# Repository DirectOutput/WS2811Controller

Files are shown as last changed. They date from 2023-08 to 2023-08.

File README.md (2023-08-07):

# WS2811 Controller
Source Code for the Atmel based WS2811 controller.

This is just old code and board designs which I found on my backup disks. There are 3 different version of the code and several versions of the board design. In some directories there are a few word and pdf files that explain some of the details. Cant say for sure if some of all this any good and what that would be. 

The assembly code was written in Atmel Studio. The boards where made with Eagle.

Feel free to use it in any way you like. Unfortunately, I cant really help with questions, since I have not touched all this for the last 8 years.

7.8.2023

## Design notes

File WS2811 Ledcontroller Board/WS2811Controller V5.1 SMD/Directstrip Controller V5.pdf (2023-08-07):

# Direct Strip Controller

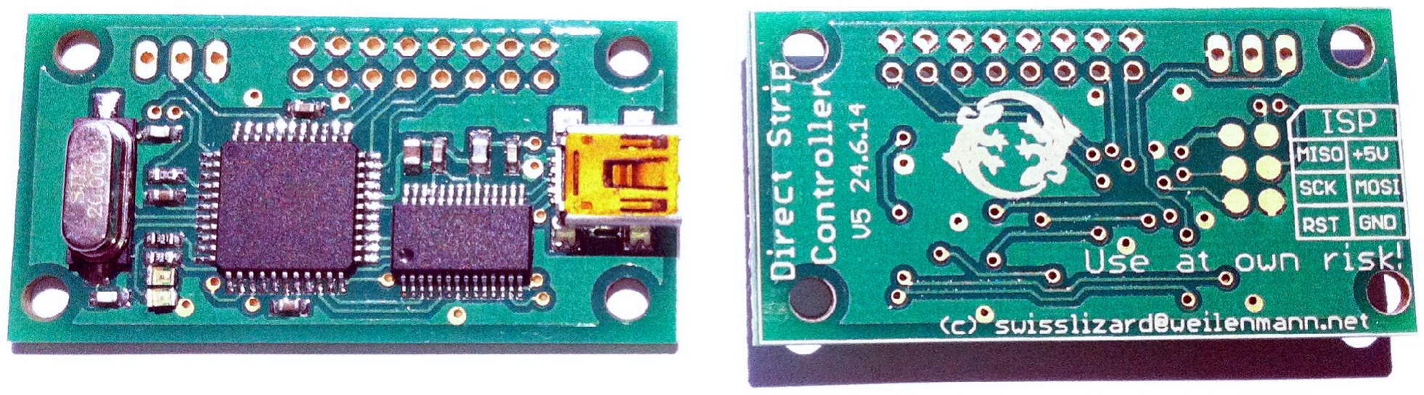
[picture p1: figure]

### made for

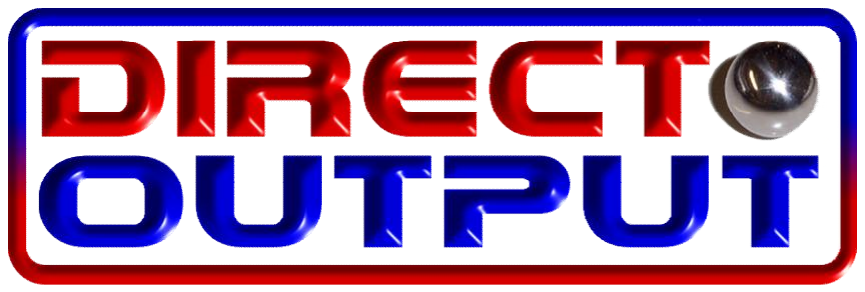
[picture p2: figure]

by

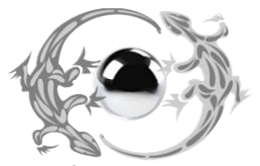
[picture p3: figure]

### Swisslizard

## Table of Contents

Direct Strip Controller | 1
Table of Contents | 2
Introduction | 3
Software | 3
Driver | 3
Firmware | 3
DirectStrip Controller Configurator | 3
Main Window | 4
Update firmware | 4
Communication Protocol | 6
Clear Data Buffer | 6
Receive Data | 6
Output Data | 7
Get Firmware Version | 7
Start Bootloader | 7
No acknowledge/Nack situations | 7
Wiring Instructions for Led Strips | 8
Step 1: Connect led strips | 8
Step 2: Connect power supply | 8
Step 3: Connect USB | 9
DirectOutput framework configuration | 10
Cabinet config file | 10
DirectStripController section | 11
LedStrip toy sections | 11
LedWizEquivalent section | 13
Table configurations | 14
Trigger parameters | 14
General parameters | 14
Matrix/area effect parameters | 15

## Introduction

This small controller boards allows you to control led strips using WS2812 or
WS2811 leds from your computer. The hardware is prepared to support other types of led strips as well, but the firmware still needs to be extended with some extra logic for those strips.

It consists of a USB chip which allows for fast communication with the PC and a Atmel micro controller which receives the data from the USB interface and generates the signal for the led strips.

## Software

### Driver

The controller board uses the FT245R chip from FTDI. To use the board you will have to install the appropriate driver, which is available for download on FTDIs page: http://www.ftdichip.com/Drivers/D2XX.htm
DOF needs only the D2XX drivers, but you might want to install the VCP drivers as well, since those are very easy to use if you want to write your own code.

### Firmware

The firmware has been developed using Atmel Studio 6, which is available from Atmels website. The firmware has been written in assembler to allow for max speed and precise cycle accurate output signals.

### DirectStrip Controller Configurator

This small tool allows you to change the number of your controller board, update the firmware and to configure the settings of a new FT245 chip so it is recognized as a DirectStrip strip controller.

Main Window

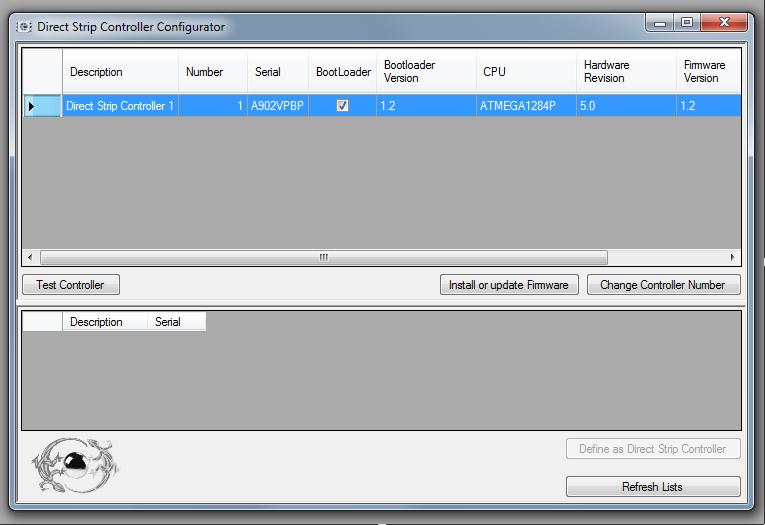
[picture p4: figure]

The upper list of the main window shows the currently detected DirectStrip controllers.
For controllers which have the bootloader installed, you can update the firmware, change the controller number and send some test patterns to a connected ledstrip.

The bottom list shows currently detected FT245 based units, including not configured DirectStrip controllers, but also other types of controllers which use the same type of hardware interface (e.g. Sainsmart). If you define a listed unit which is not a DirectStrip controller as a DirectStrip controller is might become unusable. So be sure you know what you are doing.

Update firmware
Warning!!!
Do not update your firmware for fun! The cpu of the controller has a limited number of write cycles and if something goes wrong during the firmware update your controller might become unusable.

The firmware update wizard allows you to update the firmware of you controller board in three easy steps.

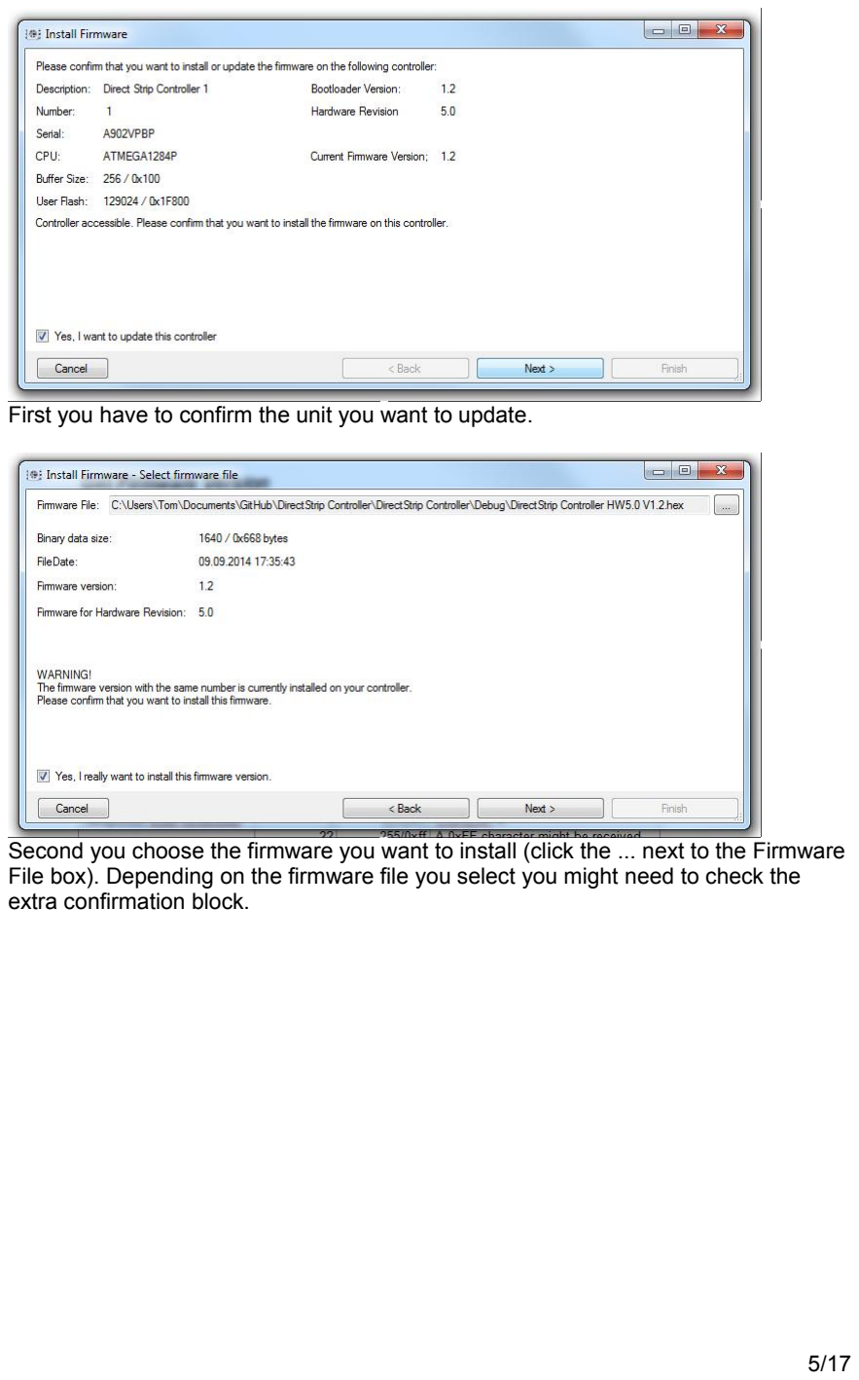
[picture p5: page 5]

First you have to confirm the unit you want to update.

Second you choose the firmware you want to install (click the ... next to the Firmware File box). Depending on the firmware file you select you might need to check the extra confirmation block.

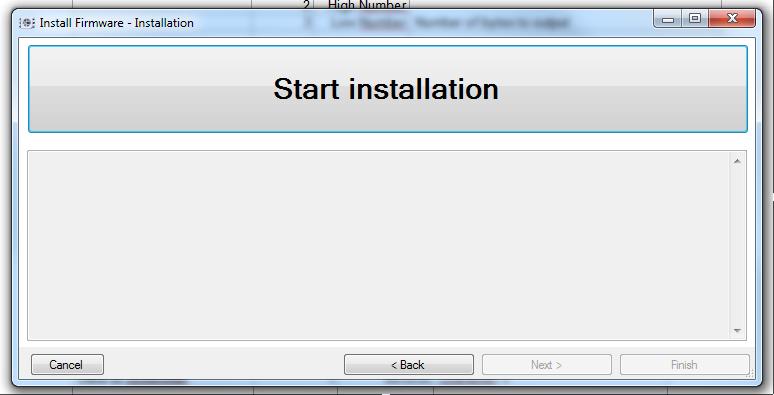
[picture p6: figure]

Third you start the installation of the firmware.
During the installation a progress bar and a log will keep you informed whats going on and whether the firmware installation has been successful or not.

## Communication Protocol

The protocol of the controller board works in a simple serial fashion. Depending on the drivers you have installed, you can even access the board like a normal com port.

All commands for the controller start with a single character, specifying the
command, followed by additional parameter bytes.
Every command is answered by the controller with single byte signalling acknowledge (A) or no acknowledge (N) of the last command.

### Clear Data Buffer

Clears the data buffer on the controller.
Byte
Nr | Value Remark
Data to controller | 1 67/0x43 Character R
Response from controller | 1 65/0x41 Character A

### Receive Data

Tells the controller to receive a block of data and put it into the data buffer.
If you write your own software it is recommended that you choose a fast implementation when using this command, since the controller is able to receive data at high rates.
| Byte Nr | Value Remark
Data to controller | 1 | 82/0x52 Character R
| 2 | High Number
| 3 | Low Number Total number of data bytes to receive
| 4 | First data byte
| 5 | Second data byte

| …. | More data bytes
| Num
| Bytes-1 | Second last data byte
| Num Bytes | Last data byte
Response from controller | 1 | 65/0x41 Character A

### Output Data

Sends data from the data buffer to the led strip. Normally this command will be used after the receive data command.

| Byte Nr | Value Remark
Data to controller | 1 | 79/0x4F Character 0
2 | High Number
| 3 | Low Number Number of bytes to output
Response from controller | 1 | 65/0x41 Ack is sent after all bytes have been sent to the led strip.

### Get Firmware Version

Gets the version of the currently installed firmware.
| Byte Nr | Value Remark
Data to controller | 1 | 86/0x56 Character V
Response from controller | 1 | 62/0x3E Character >
| 2 | 3/0x03 Number of answer bytes
3 Version major
4 Version minor 0-99
| 5 | 65/0x41 Ack

### Start Bootloader

This commands starts the bootloader of the controller board by triggering a reset of the controller. Please take note that the controller doesn't receive any data for the next 3 seconds after the ack of the command.
| Byte Nr | Value Remark
Data to controller | 1 | 90/0x5A Character Z
Response from controller | 1 | 65/0x41 Character A
2? | 255/0xff

A 0xFF character might be received depending due to pin changes during the reset.

### No acknowledge/Nack situations

If the above commands are used as expected, nack or no answer situations should at least in theory never occur. If you receive a nack anyway, there is likely a bug in your program, the firmware or less likely some problem receiving the data hardware wise. A simple procedure to react on a nack or missing answer is to send 0 bytes until another nack is received. After that second nack has been received the controller should be ready to receive the next command.

## Wiring Instructions for Led Strips

### Step 1: Connect led strips

Connect your WS2812 led strips to the controller board. You'll have to connect 2 wires: Data and Ground (GND). Both can be found on the strip connector of the controller board.

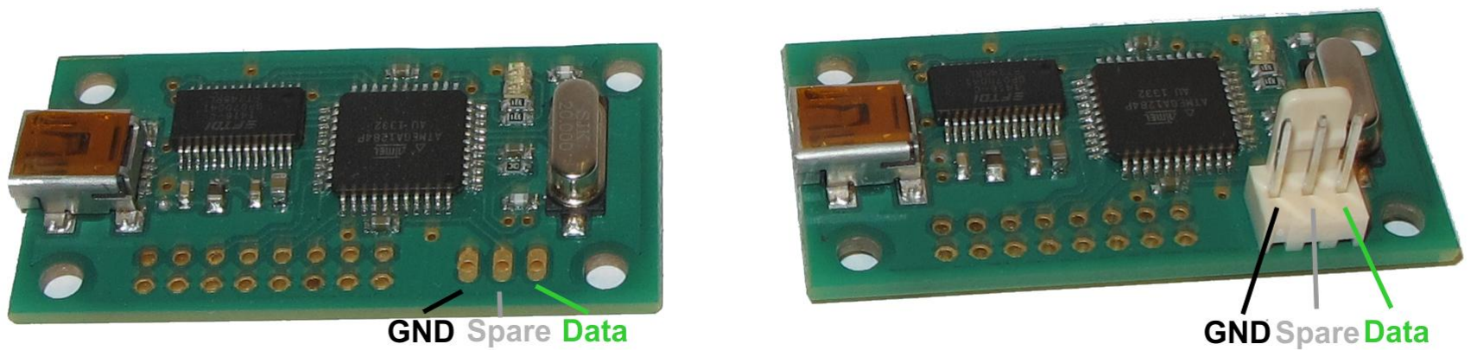
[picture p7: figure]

Warning!
Dont connect anything to the third pin marked Spare of the led strip connector. It is not yet active and reserved for possible future support of other types of led strips.

### Step 2: Connect power supply

Connect your led strips to a suitable power supply. The controller board cant supply power for the led strips and doesn't have a power connector for that purpose.

Ledstrips can consume a lot of power. Typically a led strip based on WS2812 leds will consume up to 60ma (20ma for each color) per led, e.g. if you use 1 meter of strip with 60 leds you will need a power supply which can deliver at least 3.6A (60 * 60ma=3600ma).

For me power supplies from Meanwell have always worked well so far and are available in different strengths.

Voltage for the WS2812 led strips is 5 volts.

Remarks:
- If you use a long led strip, be sure to inject power not only at the start of the strip, but also after at least every 150-200 leds. Otherwise your strip will heat up to much, brightness and color of the leds change and operation will
become unstable.
- The longer the cable from the power supply to the led strip gets and the longer the led strip is, the thicker the cable should be.
- Always keep in mind that those strips operate on 5volts only and that the currents (Ampere/A) required can be quite high. High currents can develop a lot of heat if you dont do your wiring properly!

### Step 3: Connect USB

Connect the controller board to your computer using a normal USB cable.

To start using the board check the chapter on the software in drivers.

## DirectOutput framework configuration

### Cabinet config file

To use this controller board with the DirectOutput framework (DOF) you will need a cabinet config file. The cabinet config file is a XML file with the following minimal structure:

<?xml version="1.0"?>
<Cabinet xmlns:xsi="http://www.w3.org/2001/XMLSchema-instance"xmlns:xsd="http://www.w3.org/2001/XMLSchema">
<Name>Name of the cabinet</Name>
<OutputControllers>
... configuration of any number of output controllers ... </OutputControllers>
<Toys>
... configuration of any number toys ...
</Toys>
</Cabinet>

To configure the controller board for DOF you need to specify a DirectStripController in the OutputControllers section, one or several LedStrip toys and a LezWizEquivalent toy in the Toys section.

<?xml version="1.0"?>
<Cabinet xmlns:xsi="http://www.w3.org/2001/XMLSchema-instance"xmlns:xsd="http://www.w3.org/2001/XMLSchema">
<Name>Name of the cabinet</Name>
<OutputControllers>
<DirectStripController>
<Name>ControllerName</Name> <ControllerNumber>1</ControllerNumber> <NumberOfLeds>235</NumberOfLeds> </DirectStripController>
</OutputControllers>
<Toys>
<LedStrip>
<Name>BackBoard</Name>
<Width>32</Width>
<Height>3</Height>
<LedStripArrangement>LeftRightTopDown</LedStripArrangement> <ColorOrder>GRB</ColorOrder> <FirstLedNumber>1</FirstLedNumber> <FadingCurveName>SwissLizardsLedCurve</FadingCurveName> <OutputControllerName>ControllerName</OutputControllerName> </LedStrip>
<LedStrip>
<Name>SideboardRight</Name>
<Width>1</Width>
<Height>65</Height>
<LedStripArrangement>TopDownLeftRight</LedStripArrangement> <ColorOrder>GRB</ColorOrder> <FirstLedNumber>97</FirstLedNumber> <FadingCurveName>SwissLizardsLedCurve</FadingCurveName> <OutputControllerName>ControllerName</OutputControllerName> </LedStrip>
<LedStrip>
<Name>SideboardLeft</Name>
<Width>1</Width>
<Height>65</Height>
<LedStripArrangement>TopDownLeftRight</LedStripArrangement> <ColorOrder>GRB</ColorOrder> <FirstLedNumber>167</FirstLedNumber> <FadingCurveName>SwissLizardsLedCurve</FadingCurveName> <OutputControllerName>ControllerName</OutputControllerName> </LedStrip>
<LedWizEquivalent>
<Name>LedWizEquivalent50</Name> <LedWizNumber>50</LedWizNumber> <Outputs>
<LedWizEquivalentOutput>

<OutputName>BackBoard</OutputName> <LedWizEquivalentOutputNumber>1</LedWizEquivalentOutputNumber> </LedWizEquivalentOutput>
<LedWizEquivalentOutput>
<OutputName>SideboardRight</OutputName>

<LedWizEquivalentOutputNumber>4</LedWizEquivalentOutputNumber> </LedWizEquivalentOutput>
<LedWizEquivalentOutput>
<OutputName>SideboardLeft</OutputName>

<LedWizEquivalentOutputNumber>10</LedWizEquivalentOutputNumber> </LedWizEquivalentOutput>
</Outputs>
</LedWizEquivalent>
</Toys>
</Cabinet>

DirectStripController section
The following section defines the output controller:

<DirectStripController>
<Name>ControllerName</Name> <ControllerNumber>1</ControllerNumber> <NumberOfLeds>235</NumberOfLeds> </DirectStripController>
- Name can be anything you like.
- ControllerNumber is the number of your controller board. You can use the tool supplied with the board to change the controller number of your boards.
- NumberOfLeds is the total number of RGB leds on your ledstripe. This value defines how much data DOF sends to the controller board and how much memory it reserves for the led strip data.

LedStrip toy sections
The LedStrip toy sections look a follows:

<LedStrip>
<Name>BackBoard</Name>
<Width>32</Width>
<Height>3</Height>
<LedStripArrangement>LeftRightTopDown</LedStripArrangement> <ColorOrder>GRB</ColorOrder> <FirstLedNumber>1</FirstLedNumber> <FadingCurveName>SwissLizardsLedCurve</FadingCurveName> <OutputControllerName>ControllerName</OutputControllerName> </LedStrip>
- Name can be anything you like.
- FirstLedNumber is the number of the first led of the strip which is part of the toy.
- OutputControllerName is the name of the output controller which you have defined in the DirectStripController section.
- Width and Height define the size of your led stripe arrangement. This allows you to define a matrix of leds. If you use just a single strip in your arrangement, set these values based on the main direction of your ledstrip, e.g. width: 32, height: 1 for a single strip on a backboard or width:1, height:65 for a single strip on a sideboard of your cabinet. If you have a matrix set width and height to the number of leds in x resp y direction.
- LedStripArrangement is used to tell DOF how the ledstrips in your matrix are wired. If your arrangement consist of a single strip this settings doesn't have any effect. The following values are supported:

- LeftRightTopDown
- LeftRightBottomUp
- RightLeftTopDown
- RightLeftBottomUp
- TopDownLeftRight
- TopDownRightLeft
- BottomUpLeftRight
- BottomUpRightLeft
- LeftRightAlternateTopDown
- LeftRightAlternateBottomUp
- RightLeftAlternateTopDown
- RightLeftAlternateBottomUp
- TopDownAlternateLeftRight
- TopDownAlternateRightLeft
- BottomUpAlternateLeftRight
- BottomUpAlternateRightLeft
- ColorOrder defines the order of colors of the RGB leds on your led strip. The following values are supported:
- RGB = Red-Green-Blue (usual color order)
- RBG = Red - Blue - Green
- GRB = Green - Red - Blue (WS2812 led chips are using the scheme)
- WS2812 = WS2812 led chip (uses green - red - blue color order)
- GBR = Green - Blue - Red
- BRG = Green - Blue - Red
- BGR = Blue - Green - Red
- FadingCurveName allows you to define which fading cruve to use for your leds. Fading curves can be used to adjust the brightness of the leds to the brigthness perception of the human eye or also to achieve special effects. DOF has a number of predefined fading curves, but user defined curves (see DOF docu for details) can be used as well. The following predefined curves are available:
- Linear = A linear curve, where each element will map to a value which is equal to the element index (0=0, 1=1 .... 254=254,255=255).
- Linear0To224 = A linear curve, which maps 0 to 255 value range into a new range of 0 to 224.
- Linear0To192 = A linear curve, which maps 0 to 255 value range into a new range of 0 to 192.
- Linear0To160 = A linear curve, which maps 0 to 255 value range into a new range of 0 to 160.
- Linear0To128 = A linear curve, which maps 0 to 255 value range into a new range of 0 to 128.
- Linear0To96 = A linear curve, which maps 0 to 255 value range into a new range of 0 to 96.
- Linear0To64 = A linear curve, which maps 0 to 255 value range into a new range of 0 to 64.
- Linear0To32 = A linear curve, which maps 0 to 255 value range into a new range of 0 to 32.
- Linear0To16 = A linear curve, which maps 0 to 255 value range into a new range of 0 to 16.
- InvertedLinear = This is a inverted linear curve where 255=0, 254=1 and so on until 1=254 and 0=255.

- SwissLizardsLedCurve = A fading curve for leds defined by SwissLizard. This curve is not fully correct when it comes to theoretically needed mapping values, but it is some kind of compromise between possible value range and the desired values.

LedWizEquivalent section
The LedWizEquivalent section allows DOF to map effect settings from ini files with table configurations to the led strips.

<LedWizEquivalent>
<Name>LedWizEquivalent50</Name> <LedWizNumber>50</LedWizNumber> <Outputs>
<LedWizEquivalentOutput>
<OutputName>BackBoard</OutputName> <LedWizEquivalentOutputNumber>1</LedWizEquivalentOutputNumber> </LedWizEquivalentOutput>
<LedWizEquivalentOutput>
<OutputName>SideboardRight</OutputName> <LedWizEquivalentOutputNumber>4</LedWizEquivalentOutputNumber> </LedWizEquivalentOutput>
<LedWizEquivalentOutput>
<OutputName>SideboardLeft</OutputName> <LedWizEquivalentOutputNumber>10</LedWizEquivalentOutputNumber> </LedWizEquivalentOutput>
</Outputs>
</LedWizEquivalent>
- Name can be anything you like.
- LedWizNumber is the number of the ini file to be associated with the LedWizEquivalent toy.
- The output section defines which column of the ini file is mapped to which led strip toy:
- OutputName has to specify the name of the LedStrip toy to be controlled. Take note that this is different from normal OutputName settings for LedWizEquivalent toys, where the name of a output is defined.
- LedWizEquivalentOutputNumber is column of the ini file which is to be associated with the led strip specified in OutputName.

### Table configurations

The led strips connected to the contoller board can be controlled by ini files like other toy.

The same parameters as for other toys are accepted, but the are some additional paras for toys consisting of more than one element.

Trigger parameters
The first part of a setting defines how the setting/effect is triggered and must always be one of the following:
- TableElementTypeChar plus Number (e.g. S48 for solenoid 48) determines which table element is controlling the specified effect.
- List of TableElementTypeChars plus Numbers delimited by | (e.g.
S48|W12|L59). This setting assigns the same effect to all table elements in the list.
- Condition which controlles wether the effect is triggered or not. Conditions must always be in brackets. Example: (S48=1 and W29=0 and (L59=1 or L43<>0)).
- On resp. 1 turns the specified effect constantly on.
- B defines a static (not externaly controlled) blinking.

General parameters
The second and following parts of a setting can contain one or several of the following paramaters:
- Color name as specified in the colors section of the file. Only valid as the second value (e.g. S48 Blue).
- Hex color definition (e.g. #ff0000ff for opaque red). Take note that these color definitions allow for values from 0-255 in contrast to the colors section which only support 0-48. Hex color definitions can contain 3 or 4 parts (without or with alpha value). Setting is only accepted as the second value.
- Blink defines blinking with a default interval of 500ms.
- I{Number} defines a intensity/level of the output. The number can either be specified as a decmal number between 0 (e.g. I0 for off) and 48 (e.g. I48 for fully on) or as a hexadecimal number between 00 (off) and FF (fully on) with a leading # (e.g. I#80 for 50% power). This settings does only have a effect for settings without a color definition.
- L{Number} defines the layer on which the setting operates. In most cases the setting is not required, since DOF will assign ascending layer numbers to the settings for a column anyway.
- W{NumberOfMilliseconds} defines a wait period resp. delay before the effect executes after it has been triggered.
- M{NumberOfMilliseconds} defines the minimum duration for the effect in milliseconds.
- Max{NummberOfMilliseconds} defines the maximum duration for the effect in milliseconds.
- F{NumberOfMilliseconds}, FU{NumberOfMilliseconds}, FD{NumberOfMilliseconds} are used to specify the fading duration in milliseconds. F sets the duration for both fading up and down, FU controls fading up only and FD fading down only.
- E{NumberOfMilliseconds} specifies a extended duration in milliseconds for the effect (after it has been turned off).
- BL{Number} specifies the value of the blink effect during the low period of the blinking (High value=trigger value of the effect, typicaly 255).
- BPW{Percentage} defines the blink pulse width in percent of the blink interval. Valid values are 1-99, default value if not defined is 50.
- BNP{NumberOfMilliseconds} defines the interval (duration of one on/off period) for nested blinking. This allows to define a second level of blinking within the on period of the normal blinking.
- BNPW{Percentage} defines the blink pulse width for nested blinking in percent of the blink interval.
- Invert inverts the effect, so the effect will be active when it is normaly inactive and vice versa.
- NoBool indicates that the trigger value off the effect is not to be treated as a boolean value resp. that the daufault mapping of the value to 0 or 255 (255 for all values which are not 0) should not take place. The number can either be specified as a decmal number between 0 and 48 (e.g. BL3) or as a hexadecimal number between 00 and FF with a leading # (e.g. BL#30).
- Numeric Values without any extra character can be used to specify the duration of the effect or the blinking behaviour. If blinking has been defined, one or two numeric values are parsed. Value 1 controls the blink interval in milliseconds, while value 2 defines the number of blinks. If no blinking has been defined, only one numeric values which is used to defined the duration of the effect in milliseconds is parsed.

Matrix/area effect parameters
For adressable ledstrips and other toys which implement the IMatrixToy interface the following extra parameters can be used to control the hardware referenced by the matrix. For settings controlling a matrix you have to use at least one of these paras, so DOF realizes that a matrix/area is to be controlled.

The matrix effects and parameters can be combined with the general paras mentioned above.

General Matrix Paras

The following 4 paramaters are specifying the area of a matrix which is to be influenced by a matrix effect:

- AL{LeftPosition} defines the left of the upper left corner of the area of the matrix which is to be controlled by the effect. Position is expressed in percent of the matrix width (0-100).
- AT{TopPosition} defines the upper part of the upper left corner of the area of the matrix which is to be controlled by the effect. Position is expressed in percent of the matrix height (0-100).
- AW{Width} defines the width of the area of the matrix which is to be controlled by the effect. Width is expressed in percent of the matrix width (0-100).

- AH{Height} defines the height of the area of the matrix which is to be controlled by the effect. Height is expressed in percent of the matrix height (0-100).

Shift Effect Paras
The matrix shift effect moves a color/value with a defineable direction, speed and acceleration through the matrix:
- AD{DirectionCharacter} defines the direction for area effects having a direction parameter (e.g. the ColorShiftEffect). Valid directions are: R-Right, L-Left, U-Up, D-Down.
- AS{Speed} defines the speed for matrix effects have a speed parameter (e.g. the ColorShiftEffect) expressed in percent of the effect area per second. 100 will shift through the effect area in one second, 400 will shift through the effect area in 1/4 second. Min. speed is 1, max. speed is 10000.
- AA{Acceleration} defines the acceleration of the speed for matrix effects (e.g. ColorShiftEffect), expressed in percent of the effect area per second. Acceleration can be positive (speed increases) or negative (speed decreases). Speed will never decrease below 1 and never increase above 10000.

Flicker Effect Paras
The flicker effect generates random flickering with a defineable density and duration for the single flickers:
- AFDEN{Percentage} defines the density for the flicker effect. Density is express in percent a has a valid value range of 1 to 99.
- AFMIN{DurationInMilliseconds} defines the min duration for the flicker of a single led in milliseconds.
- AFMAX{DurationInMilliseconds} defines the max duration for the flicker of a single led in milliseconds.

Bitmap Effect Paras
DOF can display a part of a bitmap image on a matrix toy. The defined part of the bitmap is scaled to the size of the matrix, so the actual resolution of the matrix does not matter. If you specify a bitmap effect by using one of the following parameters, DOF will try to load a bitmap image (gif, png, jpg and more should all work) from the same directory as the ini file. The bitmap image has to be named like the short rom name in the first collumn of the ini file (e.g. mm.png for Medival Madness or afm.gif for Attack from Mars).
- ABL{LeftPostionInPixels} defines the left/horizontal part of the upper left corner of the part of the bitmap to be displayed. Defaults to 0 if not specified.
- ABW{WidthInPixels} defines the width of the part of the bitmap to be displayed. Defaults to the total width of the image if not specified.
- ABT{TopPositionInPixels} defines the upper/vertical part of the upper left corner of the part of the bitmap to be displayed. Defaults to 0 if not specified.
- ABH{HeightInPixels} specifies the height of the part of the bitmap to be displayed. Defaults to the total height of the image if not specified.
- ABF{FrameNumber} indicates the frame of the image to be displayed. This setting is only relevant if you use animated gif images. Defaults to the first frame of the animated gif if not specified.

Bitmap Animation Paras
The following extra paras can be used in addition to the bitmap paras to animate the bitmap display on the matrix:
- AAC{CountOfFrames} specifies the total number of frames of the animation.
- AAF{FramesPerSecond} specifies the number of frames per second.
- AAD{FrameExtractionDirectionCharacter} defines the direction in which DOF moves through the source image to generate the animation. Valid values for the direction character are L=Left, D=Down, F=Frame (for animated gifs)
- AAS{FrameExtrationStepSize} defines the size of the steps DOF takes to move through the source image to generate the animation. The step size is either in pixels or in frames.
- AAB{AnimationBehaviourCharacter} defines the behaviour when the animation is triggered. Valid values are O=show animation once, L=Start at beginning and show animation in a loop (default), C=Continue at last position and show animation in a loop

The following image might give a a better idea what these parameters do. It shows the behaviour for a setting like S48 AL0 AT10 AW100 AH20 AAC116 AADD AAS5 AAF30 AABL.

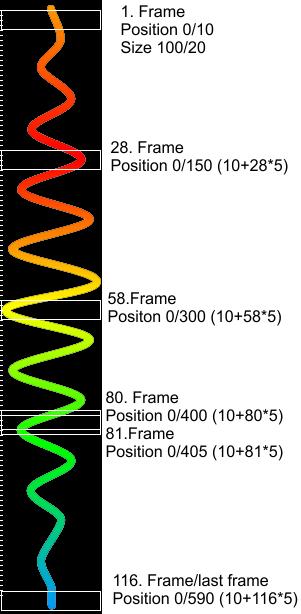
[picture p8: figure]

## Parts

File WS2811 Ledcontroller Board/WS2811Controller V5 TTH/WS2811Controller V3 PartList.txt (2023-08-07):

Partlist

Exported from WS2811Controller.sch at 29.04.2014 12:13:41

EAGLE Version 6.4.0 Copyright (c) 1988-2013 CadSoft

Assembly variant: 

Part             Value                 Device                Package                Library          Sheet

AVR-ISP                                AVR-ISP-6             AVR-ISP-6              0_avr            1
C1               100nF                 C-EU025-025X050       C025-025X050           0_Standard-Parts 1
C2               22pf                  C-EU025-025X050       C025-025X050           0_Standard-Parts 1
C3               22pf                  C-EU025-025X050       C025-025X050           0_Standard-Parts 1
C4               100nF                 C-EU025-025X050       C025-025X050           0_Standard-Parts 1
EXTCONNECTOR                           22-27-2101-10         6410-10                con-molex        1
IC1              MEGA164P/324P/644P-PU MEGA164P/324P/644P-PU DIL40                  0_avr            1
LED1                                   LED3MM                LED3MM                 0_Led            1
LED2                                   LED3MM                LED3MM                 0_Led            1
Q1               20Mhz                 CRYSTALHC49U-V        HC49U-V                0_tom parts      1
R1               10k                   R-EU_0207/10          0207/10                0_Standard-Parts 1
R2               330                   R-EU_0207/10          0207/10                0_Standard-Parts 1
R3               330                   R-EU_0207/10          0207/10                0_Standard-Parts 1
SPARKFUN_FT245RL                       FT245RL_BREAKOUTBOARD SPARKFUN_FT245RL_BOARD Sparkfun         1
STRIP1                                 22-27-2031-03         6410-03                con-molex        1

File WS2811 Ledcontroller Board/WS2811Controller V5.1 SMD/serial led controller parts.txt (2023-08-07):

Partlist

Exported from serial led controller.brd at 24.06.2014 08:57:33

EAGLE Version 6.4.0 Copyright (c) 1988-2013 CadSoft

Assembly variant: 

Part            Value                 Package      Library          Position (inch)       Orientation

+5V                                   TP19R        testpad          (0.425 0.6)           MR270
C1              100nF                 C0603K       rcl              (0.8125 0.7)          R180
C2              22pf                  C0603K       rcl              (0.28125 0.125)       R180
C3              22pf                  C0603K       rcl              (0.40625 0.625)       R180
C4              10n                   C0603K       rcl              (1.4125 0.5625)       R270
C5              100nF                 C0603K       rcl              (0.425 0.43125)       R180
C6              100nF                 C0603K       rcl              (1.2 0.5625)          R270
C7              10uf                  C0603K       rcl              (1.125 0.5625)        R270
C8              100nF                 C0603K       rcl              (0.7875 0.1)          R0
EXT_PORT                              2X08         pinhead          (1.15 0.85)           R0
GND                                   TP19R        testpad          (0.425 0.4)           MR270
IC1             MEGA1284              TQFP44       0_avr            (0.775 0.4)           R0
IC2             FT245RL               SSOP28DB     ftdichip-3       (1.275 0.3)           R0
L1              BLM21AG 601           L805         0_Standard-Parts (1.31875 0.56875)     R270
LED1Y           Yellow                CHIP-LED0603 led              (0.425 0.1375)        R270
LED2R           Red                   CHIP-LED0603 led              (0.425 0.1875)        R270
MISO                                  TP19R        testpad          (0.525 0.6)           MR270
MOSI                                  TP19R        testpad          (0.425 0.5)           MR270
Q1              20Mhz                 SM49         crystal          (0.24375 0.45625)     R90
R1              10k                   R0603        0_Standard-Parts (0.425 0.49375)       R0
R2              330                   R0603        0_Standard-Parts (0.425 0.3)           R180
R3              330                   R0603        0_Standard-Parts (0.425 0.24375)       R180
RST                                   TP19R        testpad          (0.525 0.4)           MR270
SCK                                   TP19R        testpad          (0.525 0.5)           MR270
STRIP_CONNECTOR                       6410-03      con-molex        (0.45 0.85)           R180
X1              MINI-USB-UX60A-MB-5ST UX60A-MB-5ST con-hirose       (1.65 0.4875)         R180

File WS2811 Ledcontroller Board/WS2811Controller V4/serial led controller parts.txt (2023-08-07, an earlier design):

Partlist

Exported from serial led controller.brd at 05.06.2014 11:07:59

EAGLE Version 6.4.0 Copyright (c) 1988-2013 CadSoft

Assembly variant: 

Part            Value                 Package      Library          Position (mm)         Orientation

C1              100nF                 C0603K       rcl              (20.6375 17.78)       R180
C2              22pf                  C0603K       rcl              (7.14375 3.175)       R180
C3              22pf                  C0603K       rcl              (10.31875 15.875)     R180
C4              10n                   C0603K       rcl              (35.8775 14.2875)     R270
C5              100nF                 C0603K       rcl              (10.795 10.95375)     R180
C6              100nF                 C0603K       rcl              (30.48 14.2875)       R270
C7              10uf                  C0603K       rcl              (28.575 14.2875)      R270
C8              100nF                 C0603K       rcl              (20.0025 2.54)        R0
IC1             ATMEGA1284            TQFP44       0_avr            (19.685 10.16)        R0
IC2             FT245RL               SSOP28DB     ftdichip-3       (32.385 7.62)         R0
L1              1.5A/307              R0603        0_Standard-Parts (33.655 14.2875)      R270
LED1                                  CHIP-LED0603 led              (10.795 3.4925)       R270
LED2                                  CHIP-LED0603 led              (10.795 4.7625)       R270
Q1              20Mhz                 SM49         crystal          (6.19125 11.58875)    R90
R1              10k                   R0603        0_Standard-Parts (10.795 12.54125)     R0
R2              330                   R0603        0_Standard-Parts (10.795 7.62)         R180
R3              330                   R0603        0_Standard-Parts (10.795 6.19125)      R180
RST                                   TP19R        testpad          (13.335 10.16)        MR270
SCK                                   TP19R        testpad          (13.335 12.7)         MR270
X1              MINI-USB-UX60A-MB-5ST UX60A-MB-5ST con-hirose       (41.91 12.3825)       R180
STRIP_CONNECTOR                       6410-03      con-molex        (11.43 21.59)         R180
EXT_PORT                              2X08         pinhead          (29.21 21.59)         R0

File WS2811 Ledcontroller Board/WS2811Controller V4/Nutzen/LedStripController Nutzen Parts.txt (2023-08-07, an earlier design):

Partlist

Exported from LedStripController Nutzen.brd at 05.06.2014 10:45:40

EAGLE Version 6.4.0 Copyright (c) 1988-2013 CadSoft

Assembly variant: 

Part             Value                 Package      Library          Position (inch)       Orientation

C1               100nF                 C0603K       rcl              (0.8125 0.7)          R180
C2               22pf                  C0603K       rcl              (0.28125 0.125)       R180
C3               22pf                  C0603K       rcl              (0.40625 0.625)       R180
C4               10n                   C0603K       rcl              (1.4125 0.5625)       R270
C5               100nF                 C0603K       rcl              (0.425 0.43125)       R180
C6               100nF                 C0603K       rcl              (1.2 0.5625)          R270
C7               10uf                  C0603K       rcl              (1.125 0.5625)        R270
C8               100nF                 C0603K       rcl              (0.7875 0.1)          R0
C9               100nF                 C0603K       rcl              (2.7625 0.7)          R180
C10              22pf                  C0603K       rcl              (2.23125 0.125)       R180
C11              22pf                  C0603K       rcl              (2.35625 0.625)       R180
C12              10n                   C0603K       rcl              (3.3625 0.5625)       R270
C13              100nF                 C0603K       rcl              (3.15 0.5625)         R270
C14              10uf                  C0603K       rcl              (3.075 0.5625)        R270
C15              100nF                 C0603K       rcl              (2.375 0.43125)       R180
C16              100nF                 C0603K       rcl              (2.7375 0.1)          R0
C17              100nF                 C0603K       rcl              (0.8125 1.75)         R180
C18              22pf                  C0603K       rcl              (0.28125 1.175)       R180
C19              22pf                  C0603K       rcl              (0.40625 1.675)       R180
C20              10n                   C0603K       rcl              (1.4125 1.6125)       R270
C21              100nF                 C0603K       rcl              (1.2 1.6125)          R270
C22              10uf                  C0603K       rcl              (1.125 1.6125)        R270
C23              100nF                 C0603K       rcl              (0.425 1.48125)       R180
C24              100nF                 C0603K       rcl              (0.7875 1.15)         R0
C25              100nF                 C0603K       rcl              (2.7625 1.75)         R180
C26              22pf                  C0603K       rcl              (2.23125 1.175)       R180
C27              22pf                  C0603K       rcl              (2.35625 1.675)       R180
C28              10n                   C0603K       rcl              (3.3625 1.6125)       R270
C29              100nF                 C0603K       rcl              (3.15 1.6125)         R270
C30              10uf                  C0603K       rcl              (3.075 1.6125)        R270
C31              100nF                 C0603K       rcl              (2.375 1.48125)       R180
C32              100nF                 C0603K       rcl              (2.7375 1.15)         R0
C33              100nF                 C0603K       rcl              (0.8125 2.8)          R180
C34              22pf                  C0603K       rcl              (0.28125 2.225)       R180
C35              22pf                  C0603K       rcl              (0.40625 2.725)       R180
C36              10n                   C0603K       rcl              (1.4125 2.6625)       R270
C37              100nF                 C0603K       rcl              (1.2 2.6625)          R270
C38              10uf                  C0603K       rcl              (1.125 2.6625)        R270
C39              100nF                 C0603K       rcl              (0.425 2.53125)       R180
C40              100nF                 C0603K       rcl              (0.7875 2.2)          R0
C41              100nF                 C0603K       rcl              (2.7625 2.8)          R180
C42              22pf                  C0603K       rcl              (2.23125 2.225)       R180
C43              22pf                  C0603K       rcl              (2.35625 2.725)       R180
C44              10n                   C0603K       rcl              (3.3625 2.6625)       R270
C45              100nF                 C0603K       rcl              (3.15 2.6625)         R270
C46              10uf                  C0603K       rcl              (3.075 2.6625)        R270
C47              100nF                 C0603K       rcl              (2.375 2.53125)       R180
C48              100nF                 C0603K       rcl              (2.7375 2.2)          R0
C49              100nF                 C0603K       rcl              (0.8125 3.85)         R180
C50              22pf                  C0603K       rcl              (0.28125 3.275)       R180
C51              22pf                  C0603K       rcl              (0.40625 3.775)       R180
C52              10n                   C0603K       rcl              (1.4125 3.7125)       R270
C53              100nF                 C0603K       rcl              (1.2 3.7125)          R270
C54              10uf                  C0603K       rcl              (1.125 3.7125)        R270
C55              100nF                 C0603K       rcl              (0.425 3.58125)       R180
C56              100nF                 C0603K       rcl              (0.7875 3.25)         R0
C57              100nF                 C0603K       rcl              (2.7625 3.85)         R180
C58              22pf                  C0603K       rcl              (2.23125 3.275)       R180
C59              22pf                  C0603K       rcl              (2.35625 3.775)       R180
C60              10n                   C0603K       rcl              (3.3625 3.7125)       R270
C61              100nF                 C0603K       rcl              (3.15 3.7125)         R270
C62              10uf                  C0603K       rcl              (3.075 3.7125)        R270
C63              100nF                 C0603K       rcl              (2.375 3.58125)       R180
C64              100nF                 C0603K       rcl              (2.7375 3.25)         R0
C65              100nF                 C0603K       rcl              (0.8125 4.9)          R180
C66              22pf                  C0603K       rcl              (0.28125 4.325)       R180
C67              22pf                  C0603K       rcl              (0.40625 4.825)       R180
C68              10n                   C0603K       rcl              (1.4125 4.7625)       R270
C69              100nF                 C0603K       rcl              (1.2 4.7625)          R270
C70              10uf                  C0603K       rcl              (1.125 4.7625)        R270
C71              100nF                 C0603K       rcl              (0.425 4.63125)       R180
C72              100nF                 C0603K       rcl              (0.7875 4.3)          R0
C73              100nF                 C0603K       rcl              (2.7625 4.9)          R180
C74              22pf                  C0603K       rcl              (2.23125 4.325)       R180
C75              22pf                  C0603K       rcl              (2.35625 4.825)       R180
C76              10n                   C0603K       rcl              (3.3625 4.7625)       R270
C77              100nF                 C0603K       rcl              (3.15 4.7625)         R270
C78              10uf                  C0603K       rcl              (3.075 4.7625)        R270
C79              100nF                 C0603K       rcl              (2.375 4.63125)       R180
C80              100nF                 C0603K       rcl              (2.7375 4.3)          R0

IC1              MEGA1284              TQFP44       0_avr            (0.775 0.4)           R0
IC2              FT245RL               SSOP28DB     ftdichip-3       (1.275 0.3)           R0
IC3              FT245RL               SSOP28DB     ftdichip-3       (3.225 0.3)           R0
IC4              MEGA1284              TQFP44       0_avr            (2.725 0.4)           R0
IC5              FT245RL               SSOP28DB     ftdichip-3       (1.275 1.35)          R0
IC6              MEGA1284              TQFP44       0_avr            (0.775 1.45)          R0
IC7              FT245RL               SSOP28DB     ftdichip-3       (3.225 1.35)          R0
IC8              MEGA1284              TQFP44       0_avr            (2.725 1.45)          R0
IC9              FT245RL               SSOP28DB     ftdichip-3       (1.275 2.4)           R0
IC10             MEGA1284              TQFP44       0_avr            (0.775 2.5)           R0
IC11             FT245RL               SSOP28DB     ftdichip-3       (3.225 2.4)           R0
IC12             MEGA1284              TQFP44       0_avr            (2.725 2.5)           R0
IC13             FT245RL               SSOP28DB     ftdichip-3       (1.275 3.45)          R0
IC14             MEGA1284              TQFP44       0_avr            (0.775 3.55)          R0
IC15             FT245RL               SSOP28DB     ftdichip-3       (3.225 3.45)          R0
IC16             MEGA1284              TQFP44       0_avr            (2.725 3.55)          R0
IC17             FT245RL               SSOP28DB     ftdichip-3       (1.275 4.5)           R0
IC18             MEGA1284              TQFP44       0_avr            (0.775 4.6)           R0
IC19             FT245RL               SSOP28DB     ftdichip-3       (3.225 4.5)           R0
IC20             MEGA1284              TQFP44       0_avr            (2.725 4.6)           R0
L1               1.5A/307              R0603        0_Standard-Parts (1.325 0.5625)        R270
L2               1.5A/307              R0603        0_Standard-Parts (3.275 0.5625)        R270
L3               1.5A/307              R0603        0_Standard-Parts (1.325 1.6125)        R270
L4               1.5A/307              R0603        0_Standard-Parts (3.275 1.6125)        R270
L5               1.5A/307              R0603        0_Standard-Parts (1.325 2.6625)        R270
L6               1.5A/307              R0603        0_Standard-Parts (3.275 2.6625)        R270
L7               1.5A/307              R0603        0_Standard-Parts (1.325 3.7125)        R270
L8               1.5A/307              R0603        0_Standard-Parts (3.275 3.7125)        R270
L9               1.5A/307              R0603        0_Standard-Parts (1.325 4.7625)        R270
L10              1.5A/307              R0603        0_Standard-Parts (3.275 4.7625)        R270
LED1                                   CHIP-LED0603 led              (0.425 0.1375)        R270
LED2                                   CHIP-LED0603 led              (0.425 0.1875)        R270
LED3                                   CHIP-LED0603 led              (2.375 0.1375)        R270
LED4                                   CHIP-LED0603 led              (2.375 0.1875)        R270
LED5                                   CHIP-LED0603 led              (0.425 1.1875)        R270
LED6                                   CHIP-LED0603 led              (0.425 1.2375)        R270
LED7                                   CHIP-LED0603 led              (2.375 1.1875)        R270
LED8                                   CHIP-LED0603 led              (2.375 1.2375)        R270
LED9                                   CHIP-LED0603 led              (0.425 2.2375)        R270
LED10                                  CHIP-LED0603 led              (0.425 2.2875)        R270
LED11                                  CHIP-LED0603 led              (2.375 2.2375)        R270
LED12                                  CHIP-LED0603 led              (2.375 2.2875)        R270
LED13                                  CHIP-LED0603 led              (0.425 3.2875)        R270
LED14                                  CHIP-LED0603 led              (0.425 3.3375)        R270
LED15                                  CHIP-LED0603 led              (2.375 3.2875)        R270
LED16                                  CHIP-LED0603 led              (2.375 3.3375)        R270
LED17                                  CHIP-LED0603 led              (0.425 4.3375)        R270
LED18                                  CHIP-LED0603 led              (0.425 4.3875)        R270
LED19                                  CHIP-LED0603 led              (2.375 4.3375)        R270
LED20                                  CHIP-LED0603 led              (2.375 4.3875)        R270
Q1               20Mhz                 SM49         crystal          (0.24375 0.45625)     R90
Q2               20Mhz                 SM49         crystal          (2.19375 0.45625)     R90
Q3               20Mhz                 SM49         crystal          (0.24375 1.50625)     R90
Q4               20Mhz                 SM49         crystal          (2.19375 1.50625)     R90
Q5               20Mhz                 SM49         crystal          (0.24375 2.55625)     R90
Q6               20Mhz                 SM49         crystal          (2.19375 2.55625)     R90
Q7               20Mhz                 SM49         crystal          (0.24375 3.60625)     R90
Q8               20Mhz                 SM49         crystal          (2.19375 3.60625)     R90
Q9               20Mhz                 SM49         crystal          (0.24375 4.65625)     R90
Q10              20Mhz                 SM49         crystal          (2.19375 4.65625)     R90
R1               10k                   R0603        0_Standard-Parts (0.425 0.49375)       R0
R2               330                   R0603        0_Standard-Parts (0.425 0.3)           R180
R3               330                   R0603        0_Standard-Parts (0.425 0.24375)       R180
R4               10k                   R0603        0_Standard-Parts (2.375 0.49375)       R0
R5               330                   R0603        0_Standard-Parts (2.375 0.3)           R180
R6               330                   R0603        0_Standard-Parts (2.375 0.24375)       R180
R7               10k                   R0603        0_Standard-Parts (0.425 1.54375)       R0
R8               330                   R0603        0_Standard-Parts (0.425 1.35)          R180
R9               330                   R0603        0_Standard-Parts (0.425 1.29375)       R180
R10              10k                   R0603        0_Standard-Parts (2.375 1.54375)       R0
R11              330                   R0603        0_Standard-Parts (2.375 1.35)          R180
R12              330                   R0603        0_Standard-Parts (2.375 1.29375)       R180
R13              10k                   R0603        0_Standard-Parts (0.425 2.59375)       R0
R14              330                   R0603        0_Standard-Parts (0.425 2.4)           R180
R15              330                   R0603        0_Standard-Parts (0.425 2.34375)       R180
R16              10k                   R0603        0_Standard-Parts (2.375 2.59375)       R0
R17              330                   R0603        0_Standard-Parts (2.375 2.4)           R180
R18              330                   R0603        0_Standard-Parts (2.375 2.34375)       R180
R19              10k                   R0603        0_Standard-Parts (0.425 3.64375)       R0
R20              330                   R0603        0_Standard-Parts (0.425 3.45)          R180
R21              330                   R0603        0_Standard-Parts (0.425 3.39375)       R180
R22              10k                   R0603        0_Standard-Parts (2.375 3.64375)       R0
R23              330                   R0603        0_Standard-Parts (2.375 3.45)          R180
R24              330                   R0603        0_Standard-Parts (2.375 3.39375)       R180
R25              10k                   R0603        0_Standard-Parts (0.425 4.69375)       R0
R26              330                   R0603        0_Standard-Parts (0.425 4.5)           R180
R27              330                   R0603        0_Standard-Parts (0.425 4.44375)       R180
R28              10k                   R0603        0_Standard-Parts (2.375 4.69375)       R0
R29              330                   R0603        0_Standard-Parts (2.375 4.5)           R180
R30              330                   R0603        0_Standard-Parts (2.375 4.44375)       R180
X1               MINI-USB-UX60A-MB-5ST UX60A-MB-5ST con-hirose       (1.65 0.4875)         R180
X2               MINI-USB-UX60A-MB-5ST UX60A-MB-5ST con-hirose       (3.6 0.4875)          R180
X3               MINI-USB-UX60A-MB-5ST UX60A-MB-5ST con-hirose       (1.65 1.5375)         R180
X4               MINI-USB-UX60A-MB-5ST UX60A-MB-5ST con-hirose       (3.6 1.5375)          R180
X5               MINI-USB-UX60A-MB-5ST UX60A-MB-5ST con-hirose       (1.65 2.5875)         R180
X6               MINI-USB-UX60A-MB-5ST UX60A-MB-5ST con-hirose       (3.6 2.5875)          R180
X7               MINI-USB-UX60A-MB-5ST UX60A-MB-5ST con-hirose       (1.65 3.6375)         R180
X8               MINI-USB-UX60A-MB-5ST UX60A-MB-5ST con-hirose       (3.6 3.6375)          R180
X9               MINI-USB-UX60A-MB-5ST UX60A-MB-5ST con-hirose       (1.65 4.6875)         R180
X10              MINI-USB-UX60A-MB-5ST UX60A-MB-5ST con-hirose       (3.6 4.6875)          R180

STRIP_CONNECTOR                        6410-03      con-molex        (0.45 0.85)           R180
STRIP_CONNECTOR1                       6410-03      con-molex        (2.4 0.85)            R180
STRIP_CONNECTOR2                       6410-03      con-molex        (0.45 1.9)            R180
STRIP_CONNECTOR3                       6410-03      con-molex        (2.4 1.9)             R180
STRIP_CONNECTOR4                       6410-03      con-molex        (0.45 2.95)           R180
STRIP_CONNECTOR5                       6410-03      con-molex        (2.4 2.95)            R180
STRIP_CONNECTOR6                       6410-03      con-molex        (0.45 4)              R180
STRIP_CONNECTOR7                       6410-03      con-molex        (2.4 4)               R180
STRIP_CONNECTOR8                       6410-03      con-molex        (0.45 5.05)           R180
STRIP_CONNECTOR9                       6410-03      con-molex        (2.4 5.05)            R180
EXT_PORT                               2X08         pinhead          (1.15 0.85)           R0
EXT_PORT1                              2X08         pinhead          (3.1 0.85)            R0
EXT_PORT2                              2X08         pinhead          (1.15 1.9)            R0
EXT_PORT3                              2X08         pinhead          (3.1 1.9)             R0
EXT_PORT4                              2X08         pinhead          (1.15 2.95)           R0
EXT_PORT5                              2X08         pinhead          (3.1 2.95)            R0
EXT_PORT6                              2X08         pinhead          (1.15 4)              R0
EXT_PORT7                              2X08         pinhead          (3.1 4)               R0
EXT_PORT8                              2X08         pinhead          (1.15 5.05)           R0
EXT_PORT9                              2X08         pinhead          (3.1 5.05)            R0

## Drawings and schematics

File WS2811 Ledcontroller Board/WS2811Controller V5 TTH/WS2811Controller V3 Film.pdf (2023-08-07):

# LedStrip Controller V3

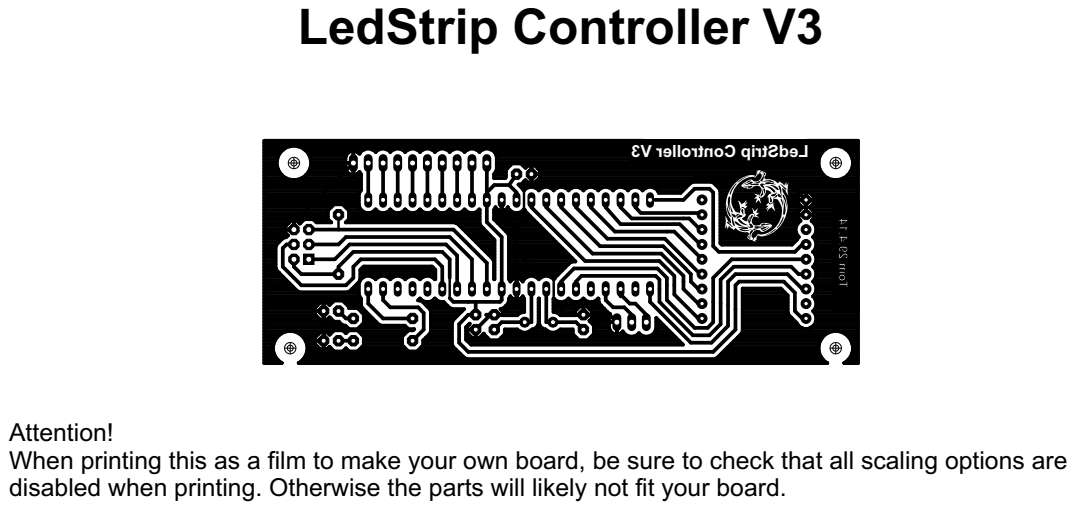
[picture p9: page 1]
Tom 29.4.14

Attention!
When printing this as a film to make your own board, be sure to check that all scaling options are
disabled when printing. Otherwise the parts will likely not fit your board.

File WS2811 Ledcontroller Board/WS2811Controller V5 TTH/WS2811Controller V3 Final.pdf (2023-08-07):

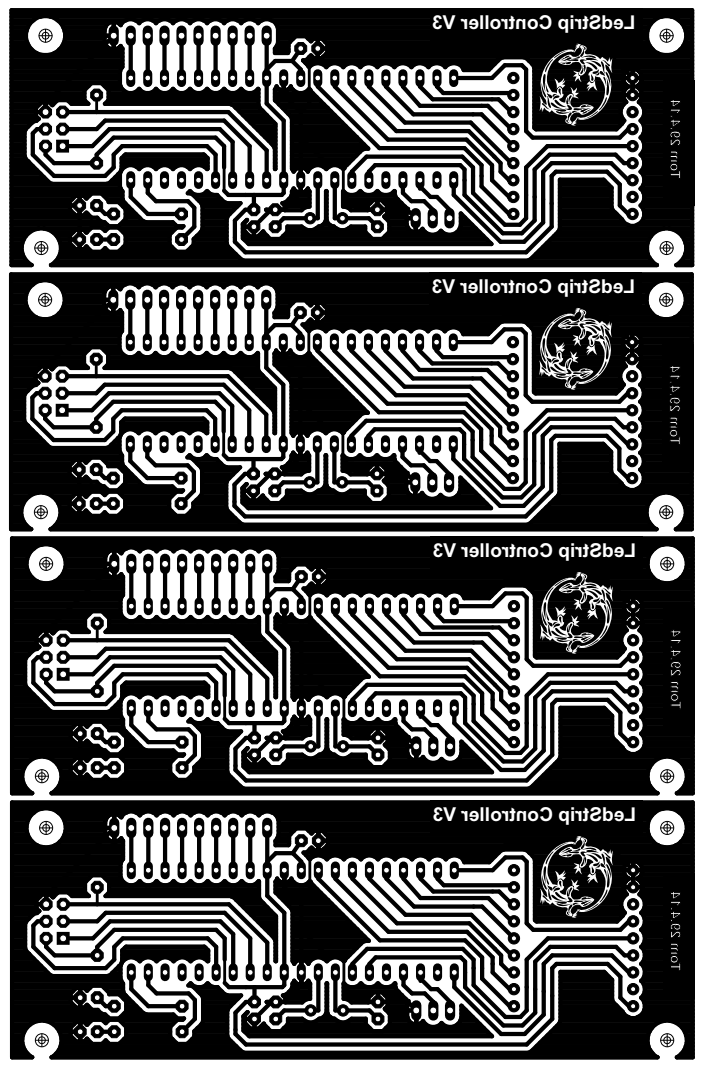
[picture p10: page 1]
Tom 29.4.14

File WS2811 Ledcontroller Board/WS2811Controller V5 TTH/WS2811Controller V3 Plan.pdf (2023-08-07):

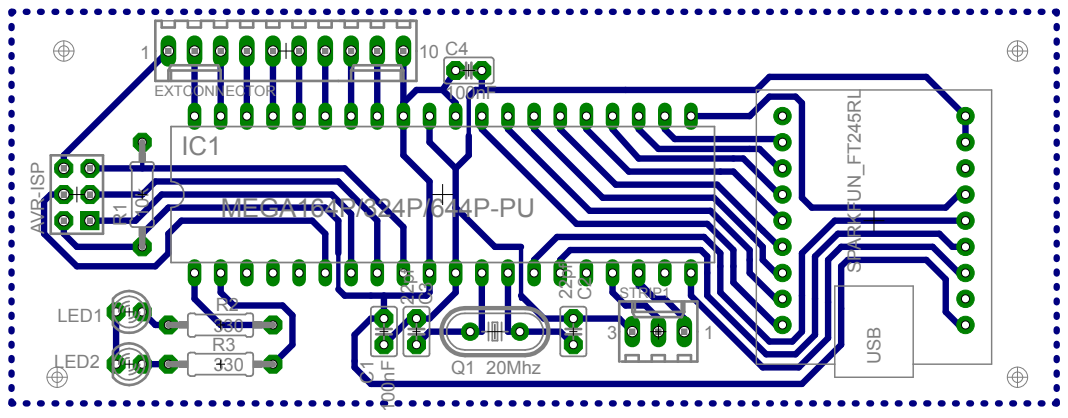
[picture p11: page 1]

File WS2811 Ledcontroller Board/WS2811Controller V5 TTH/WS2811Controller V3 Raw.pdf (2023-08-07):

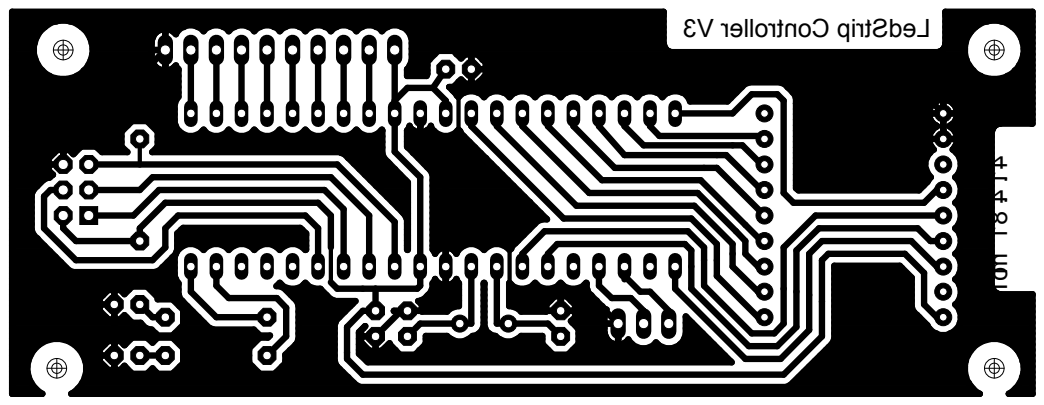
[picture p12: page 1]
Tom 18.4.14

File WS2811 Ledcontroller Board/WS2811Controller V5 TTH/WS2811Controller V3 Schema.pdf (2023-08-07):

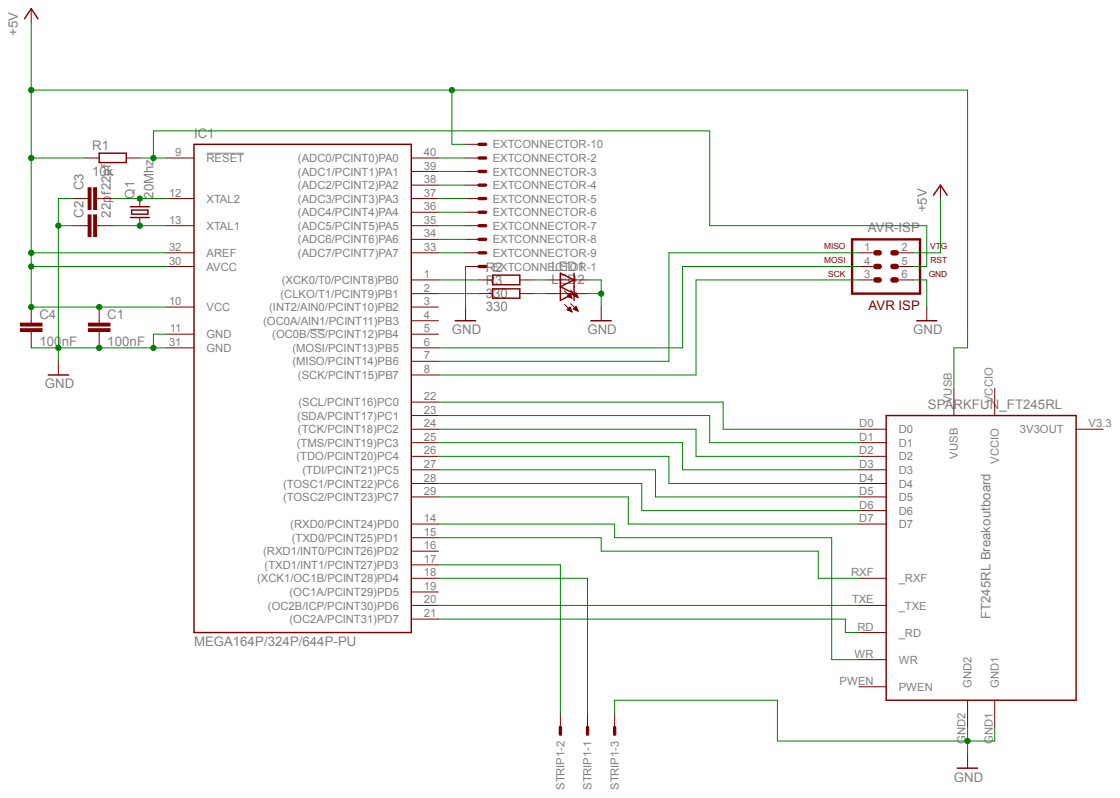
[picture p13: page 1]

100nF ²⁰Mhz 22pf22pf | XTAL1 13

AVCC 30

_RXF RXF

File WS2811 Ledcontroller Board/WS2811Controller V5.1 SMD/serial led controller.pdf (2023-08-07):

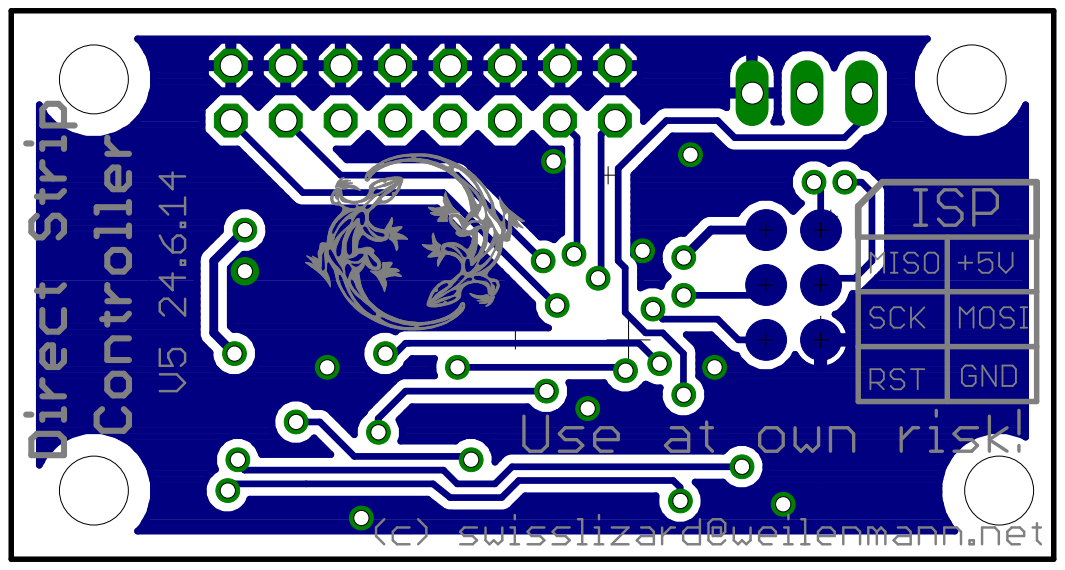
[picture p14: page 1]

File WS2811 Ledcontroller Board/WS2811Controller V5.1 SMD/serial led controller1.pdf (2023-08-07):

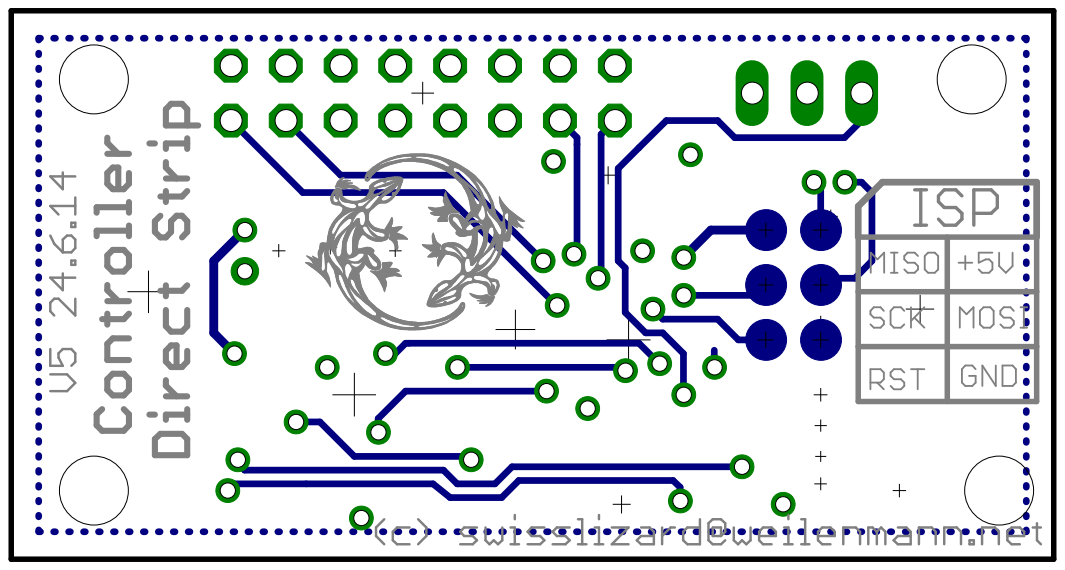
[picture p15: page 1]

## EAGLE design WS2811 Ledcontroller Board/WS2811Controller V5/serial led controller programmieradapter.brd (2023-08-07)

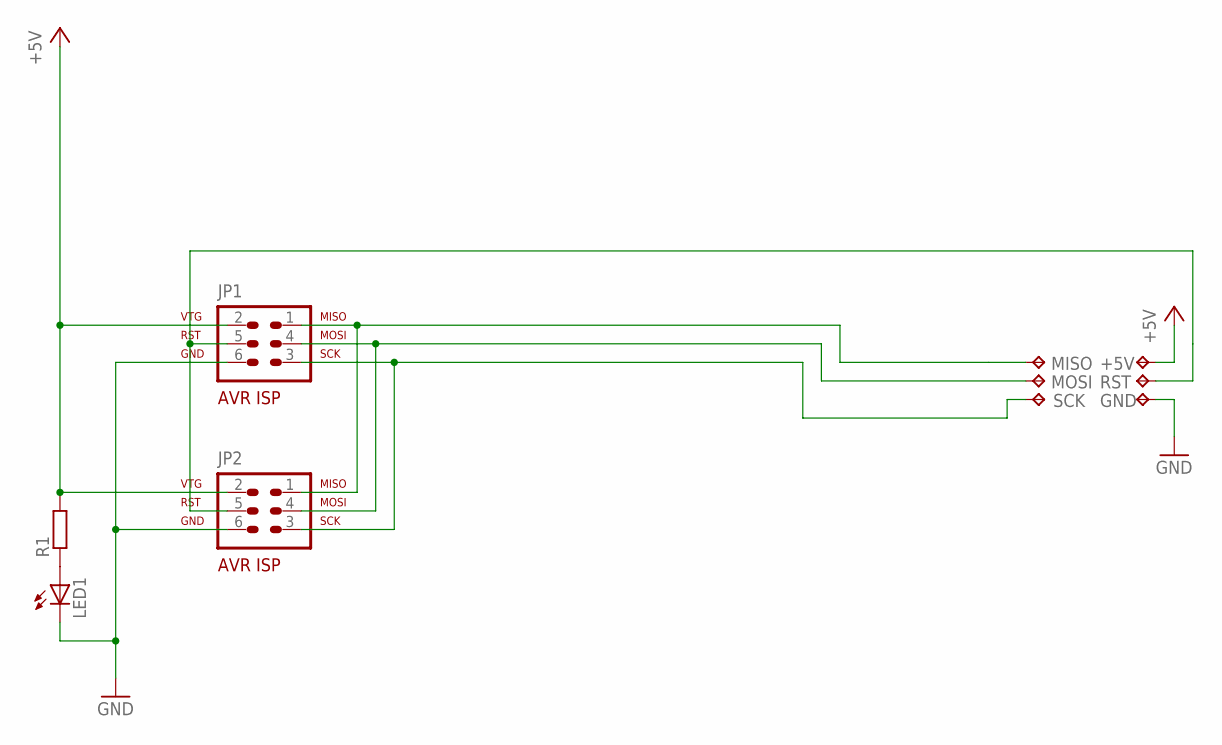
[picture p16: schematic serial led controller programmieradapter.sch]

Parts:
+5V: TPTP19R; TP19R
GND: TPTP19R; TP19R
JP1, JP2: AVR-ISP-6
LED1: LED3MM
MISO: TPTP19R; TP19R
MOSI: TPTP19R; TP19R
R1: R-EU_0207/10; 0207/10
RST: TPTP19R; TP19R
SCK: TPTP19R; TP19R

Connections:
+5V: +5V.TP, JP1.2, JP2.2, R1.2
GND: GND.TP, JP1.6, JP2.6, LED1.K (C)
MISO: JP1.1, JP2.1, MISO.TP
unnamed: LED1.A, R1.1
unnamed: JP1.4, JP2.4, MOSI.TP
RST: JP1.5, JP2.5, RST.TP
SCK: JP1.3, JP2.3, SCK.TP

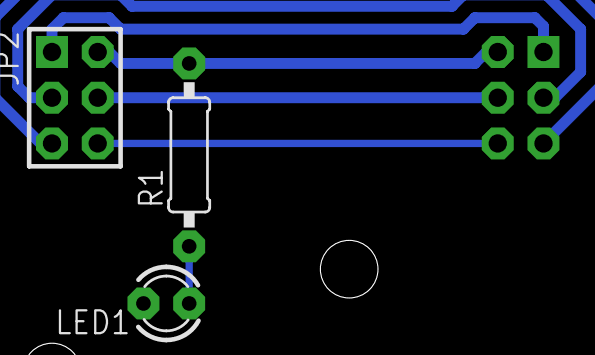
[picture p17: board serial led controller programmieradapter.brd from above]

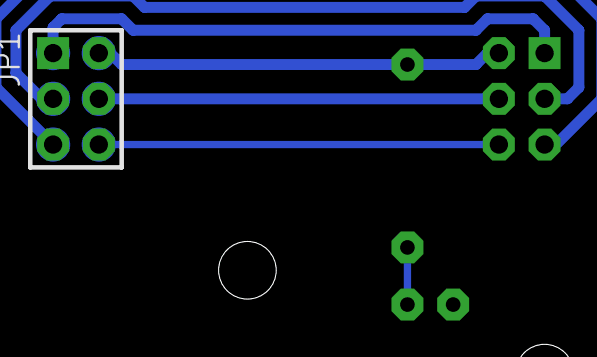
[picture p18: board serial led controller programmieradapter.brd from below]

Board: 2 copper layers, 10 parts (7 on the bottom side), 7 nets.

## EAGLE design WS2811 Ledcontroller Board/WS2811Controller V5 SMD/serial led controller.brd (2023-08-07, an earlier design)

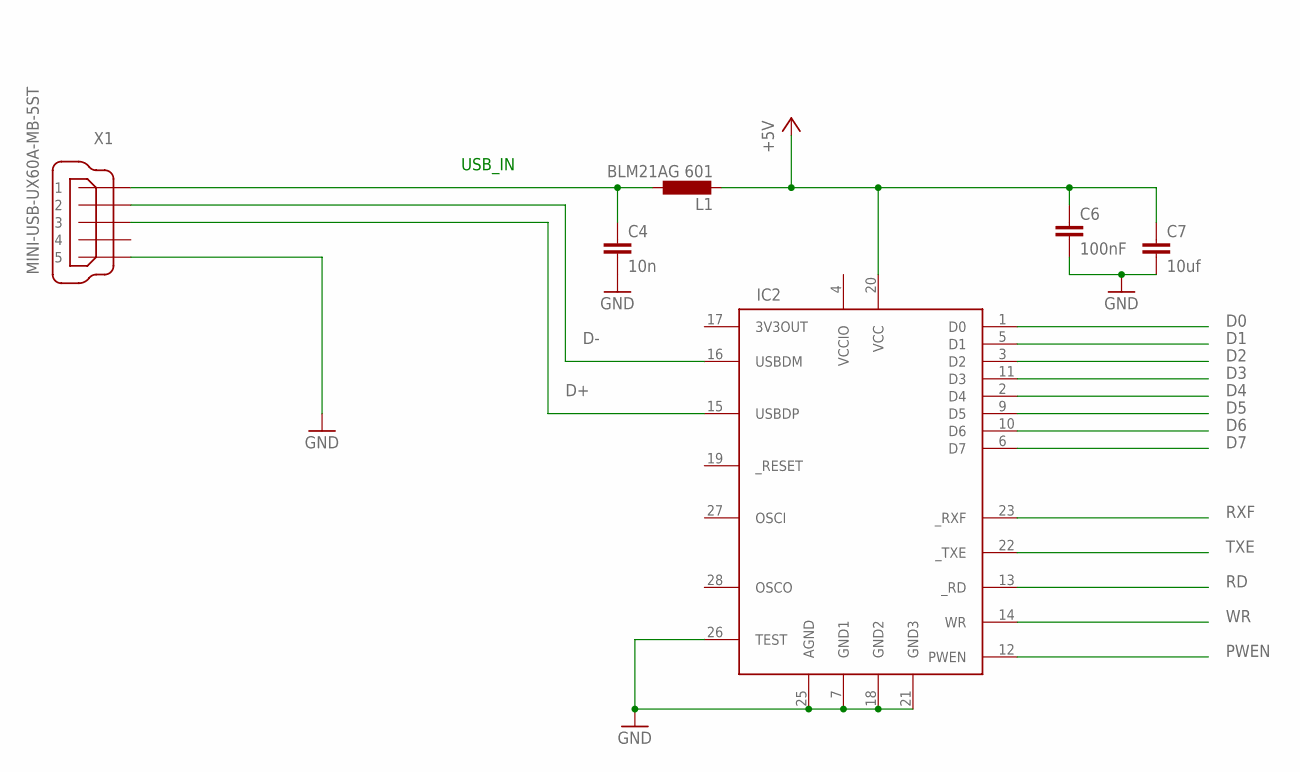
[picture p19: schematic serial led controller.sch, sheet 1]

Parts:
C4: 10n; C0603K
C6: 100nF; C0603K
C7: 10uf; C0603K
IC2: FT245RL; SSOP28DB
L1: BLM21AG 601; L805
X1: MINI-USB-UX60A-MB-5ST; UX60A-MB-5ST

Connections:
+5V: C6.1, C7.1, IC2.20 (VCC), L1.2; also elsewhere on the board
D0: IC2.1 (D0); also elsewhere on the board
D1: IC2.5 (D1); also elsewhere on the board
D2: IC2.3 (D2); also elsewhere on the board
D3: IC2.11 (D3); also elsewhere on the board
D4: IC2.2 (D4); also elsewhere on the board
D5: IC2.9 (D5); also elsewhere on the board
D6: IC2.10 (D6); also elsewhere on the board
D7: IC2.6 (D7); also elsewhere on the board
D+: IC2.15 (USBDP), X1.3
D-: IC2.16 (USBDM), X1.2
GND: C4.2, C6.2, C7.2, IC2.7 (GND1), IC2.18 (GND2), IC2.21 (GND3), IC2.25 (AGND), IC2.26 (TEST), X1.5; also elsewhere on the board
PWEN: IC2.12 (PWEN)
RD: IC2.13 (_RD); also elsewhere on the board
RXF: IC2.23 (_RXF); also elsewhere on the board
TXE: IC2.22 (_TXE); also elsewhere on the board
USBSUPPLY: C4.1, L1.1, X1.1
VCCIO: IC2.4 (VCCIO)
WR: IC2.14 (WR); also elsewhere on the board

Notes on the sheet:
USB_IN

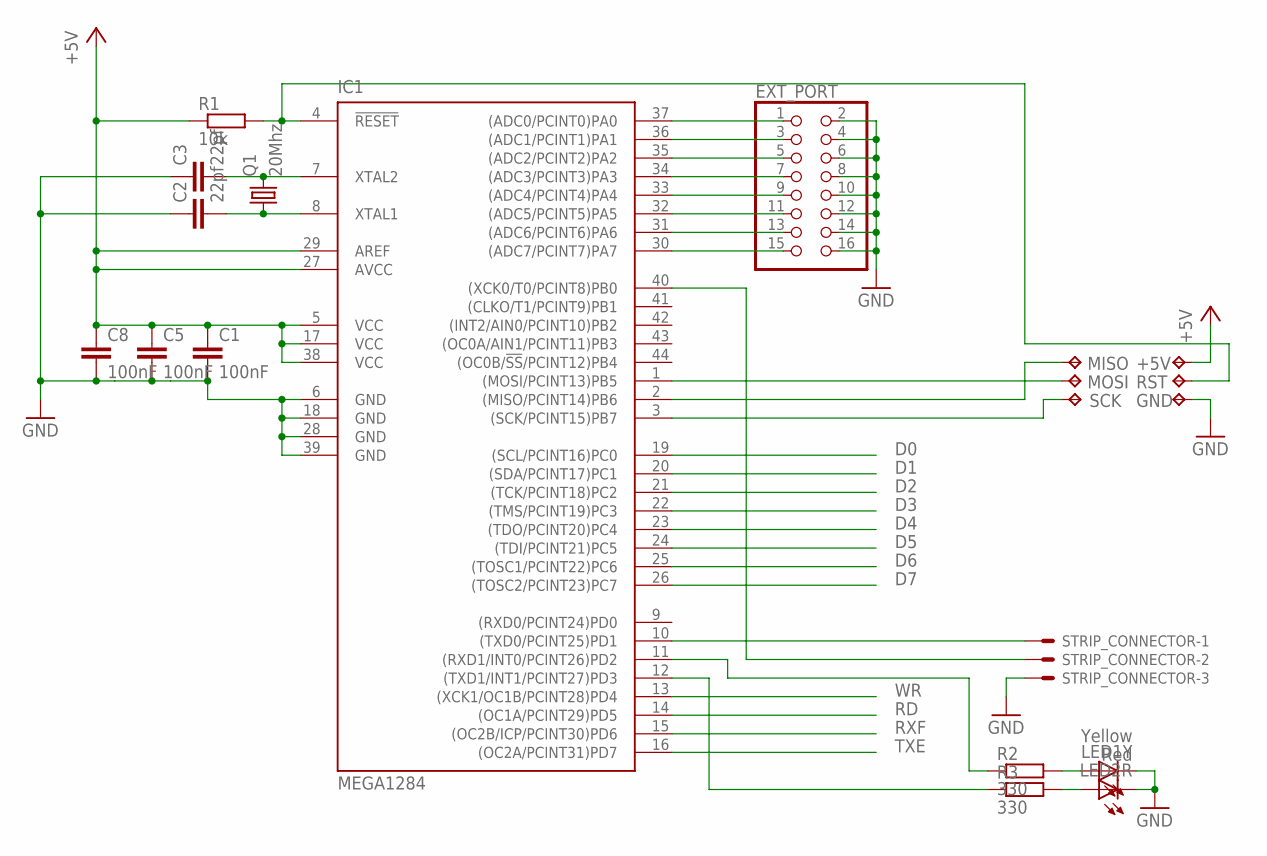
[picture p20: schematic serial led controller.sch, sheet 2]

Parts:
+5V: TPTP19R; TP19R
C1, C5, C8: 100nF; C0603K
C2, C3: 22pf; C0603K
EXT_PORT: PINHD-2X8; 2X08
GND: TPTP19R; TP19R
IC1: MEGA1284; TQFP44
LED1Y: Yellow; CHIP-LED0603
LED2R: Red; CHIP-LED0603
MISO: TPTP19R; TP19R
MOSI: TPTP19R; TP19R
Q1: 20Mhz; SM49
R1: 10k; R0603
R2, R3: 330; R0603
RST: TPTP19R; TP19R
SCK: TPTP19R; TP19R
STRIP_CONNECTOR: 22-27-2031-03; 6410-03

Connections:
+5V: +5V.TP, C1.1, C5.1, C8.1, IC1.5 (VCC), IC1.17 (VCC), IC1.27 (AVCC), IC1.29 (AREF), IC1.38 (VCC), R1.1; also elsewhere on the board
CLOCK: IC1.40 ((XCK0/T0/PCINT8)PB0), STRIP_CONNECTOR.2
D0: IC1.19 ((SCL/PCINT16)PC0); also elsewhere on the board
D1: IC1.20 ((SDA/PCINT17)PC1); also elsewhere on the board
D2: IC1.21 ((TCK/PCINT18)PC2); also elsewhere on the board
D3: IC1.22 ((TMS/PCINT19)PC3); also elsewhere on the board
D4: IC1.23 ((TDO/PCINT20)PC4); also elsewhere on the board
D5: IC1.24 ((TDI/PCINT21)PC5); also elsewhere on the board
D6: IC1.25 ((TOSC1/PCINT22)PC6); also elsewhere on the board
D7: IC1.26 ((TOSC2/PCINT23)PC7); also elsewhere on the board
DATA: IC1.10 ((TXD0/PCINT25)PD1), STRIP_CONNECTOR.1
GND: C1.2, C2.1, C3.1, C5.2, C8.2, EXT_PORT.2, EXT_PORT.4, EXT_PORT.6, EXT_PORT.8, EXT_PORT.10, EXT_PORT.12, EXT_PORT.14, EXT_PORT.16, GND.TP, IC1.6 (GND), IC1.18 (GND), IC1.28 (GND), IC1.39 (GND), LED1Y.C, LED2R.C, STRIP_CONNECTOR.3; also elsewhere on the board
MISO: IC1.2 ((MISO/PCINT14)PB6), MISO.TP
MOSI: IC1.1 ((MOSI/PCINT13)PB5), MOSI.TP
unnamed: EXT_PORT.15, IC1.30 ((ADC7/PCINT7)PA7)
unnamed: EXT_PORT.13, IC1.31 ((ADC6/PCINT6)PA6)
unnamed: IC1.11 ((RXD1/INT0/PCINT26)PD2), R2.1
unnamed: EXT_PORT.11, IC1.32 ((ADC5/PCINT5)PA5)
unnamed: EXT_PORT.9, IC1.33 ((ADC4/PCINT4)PA4)
unnamed: IC1.12 ((TXD1/INT1/PCINT27)PD3), R3.1
unnamed: EXT_PORT.7, IC1.34 ((ADC3/PCINT3)PA3)
unnamed: C2.2, IC1.8 (XTAL1), Q1.1
unnamed: C3.2, IC1.7 (XTAL2), Q1.2
unnamed: EXT_PORT.5, IC1.35 ((ADC2/PCINT2)PA2)
unnamed: EXT_PORT.3, IC1.36 ((ADC1/PCINT1)PA1)
unnamed: EXT_PORT.1, IC1.37 ((ADC0/PCINT0)PA0)
unnamed: LED1Y.A, R2.2
unnamed: LED2R.A, R3.2
RD: IC1.14 ((OC1A/PCINT29)PD5); also elsewhere on the board
RST: IC1.4 (!RESET), R1.2, RST.TP
RXF: IC1.15 ((OC2B/ICP/PCINT30)PD6); also elsewhere on the board
SCK: IC1.3 ((SCK/PCINT15)PB7), SCK.TP
TXE: IC1.16 ((OC2A/PCINT31)PD7); also elsewhere on the board
WR: IC1.13 ((XCK1/OC1B/PCINT28)PD4); also elsewhere on the board

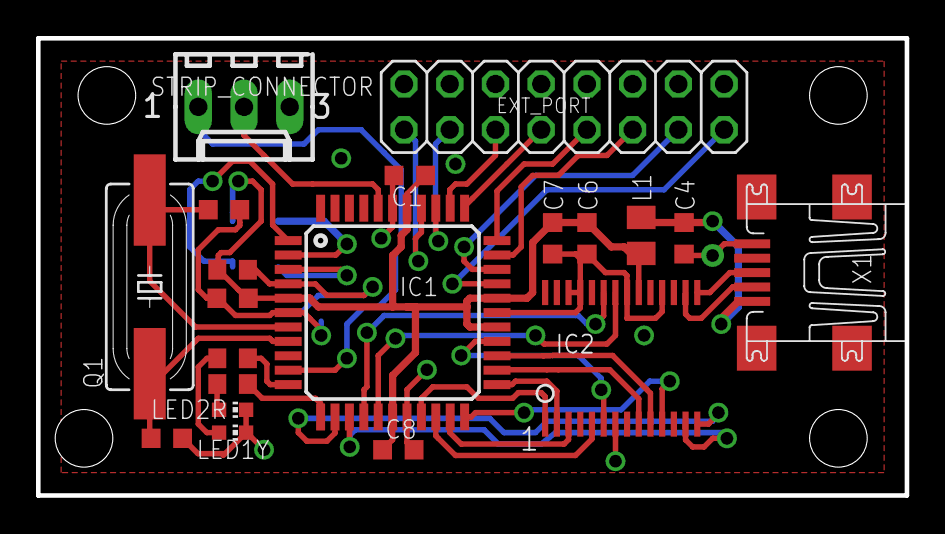
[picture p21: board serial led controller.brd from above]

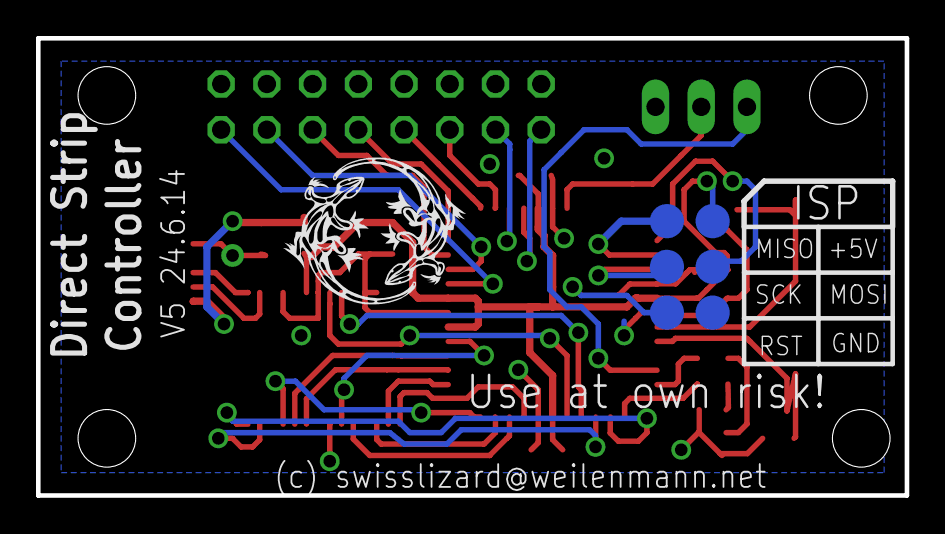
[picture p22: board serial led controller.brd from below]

Board: 2 copper layers, 48.3 x 25.4 mm, 27 parts (6 on the bottom side), 37 nets.

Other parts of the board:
U$1: DOUBLE_LIZARD_400

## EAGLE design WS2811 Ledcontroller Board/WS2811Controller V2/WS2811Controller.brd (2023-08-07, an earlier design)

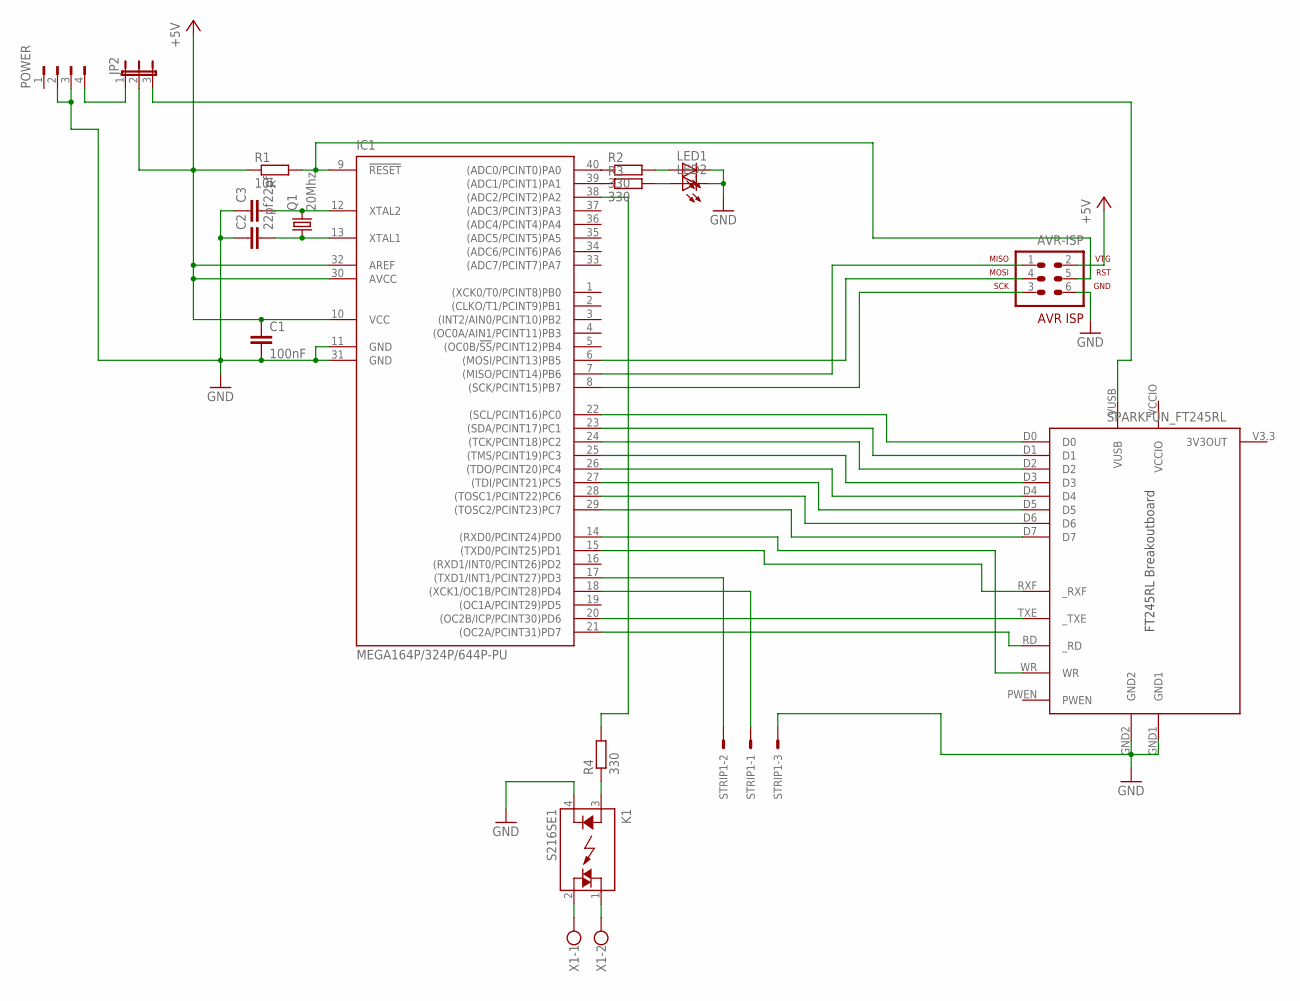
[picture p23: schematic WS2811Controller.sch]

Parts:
AVR-ISP: AVR-ISP-6
C1: 100nF; C050-030X075
C2, C3: 22pf; C050-024X044
IC1: MEGA164P/324P/644P-PU; DIL40
JP2: JP2E; JP2
K1: S216SE1; S2XXEX
LED1, LED2: LED3MM
POWER: FLOPPY-4
Q1: 20Mhz; HC49U70
R1: 10k; 0207/10
R2, R3, R4: 330; 0207/10
SPARKFUN_FT245RL: FT245RL_BREAKOUTBOARD; SPARKFUN_FT245RL_BOARD
STRIP1: 22-27-2031-03; 6410-03
X1: W237-102

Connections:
+5V: AVR-ISP.2, C1.1, IC1.10 (VCC), IC1.30 (AVCC), IC1.32 (AREF), JP2.2, R1.1
GND: AVR-ISP.6, C1.2, C2.1, C3.1, IC1.11 (GND), IC1.31 (GND), K1.4 (K), LED1.K (C), LED2.K (C), POWER.2, POWER.3, SPARKFUN_FT245RL.GND1, SPARKFUN_FT245RL.GND2, STRIP1.3
unnamed: AVR-ISP.3, IC1.8 ((SCK/PCINT15)PB7)
unnamed: AVR-ISP.1, IC1.7 ((MISO/PCINT14)PB6)
unnamed: IC1.40 ((ADC0/PCINT0)PA0), R2.1
unnamed: AVR-ISP.5, IC1.9 (!RESET), R1.2
unnamed: AVR-ISP.4, IC1.6 ((MOSI/PCINT13)PB5)
unnamed: IC1.39 ((ADC1/PCINT1)PA1), R3.1
unnamed: IC1.22 ((SCL/PCINT16)PC0), SPARKFUN_FT245RL.D0
unnamed: C2.2, IC1.13 (XTAL1), Q1.1
unnamed: C3.2, IC1.12 (XTAL2), Q1.2
unnamed: IC1.23 ((SDA/PCINT17)PC1), SPARKFUN_FT245RL.D1
unnamed: IC1.24 ((TCK/PCINT18)PC2), SPARKFUN_FT245RL.D2
unnamed: IC1.25 ((TMS/PCINT19)PC3), SPARKFUN_FT245RL.D3
unnamed: IC1.26 ((TDO/PCINT20)PC4), SPARKFUN_FT245RL.D4
unnamed: IC1.27 ((TDI/PCINT21)PC5), SPARKFUN_FT245RL.D5
unnamed: IC1.28 ((TOSC1/PCINT22)PC6), SPARKFUN_FT245RL.D6
unnamed: IC1.29 ((TOSC2/PCINT23)PC7), SPARKFUN_FT245RL.D7
unnamed: IC1.20 ((OC2B/ICP/PCINT30)PD6), SPARKFUN_FT245RL.TXE (_TXE)
unnamed: IC1.15 ((TXD0/PCINT25)PD1), SPARKFUN_FT245RL.RXF (_RXF)
unnamed: IC1.21 ((OC2A/PCINT31)PD7), SPARKFUN_FT245RL.RD (_RD)
unnamed: IC1.14 ((RXD0/PCINT24)PD0), SPARKFUN_FT245RL.WR
unnamed: LED1.A, R2.2
unnamed: LED2.A, R3.2
unnamed: IC1.18 ((XCK1/OC1B/PCINT28)PD4), STRIP1.1
unnamed: JP2.1, POWER.4
unnamed: IC1.17 ((TXD1/INT1/PCINT27)PD3), STRIP1.2
unnamed: K1.2 (DS2), X1.1
unnamed: K1.1 (DS1), X1.2
unnamed: IC1.38 ((ADC2/PCINT2)PA2), R4.2
unnamed: K1.3 (A), R4.1
unnamed: JP2.3, SPARKFUN_FT245RL.VUSB
VCCIO: SPARKFUN_FT245RL.VCCIO

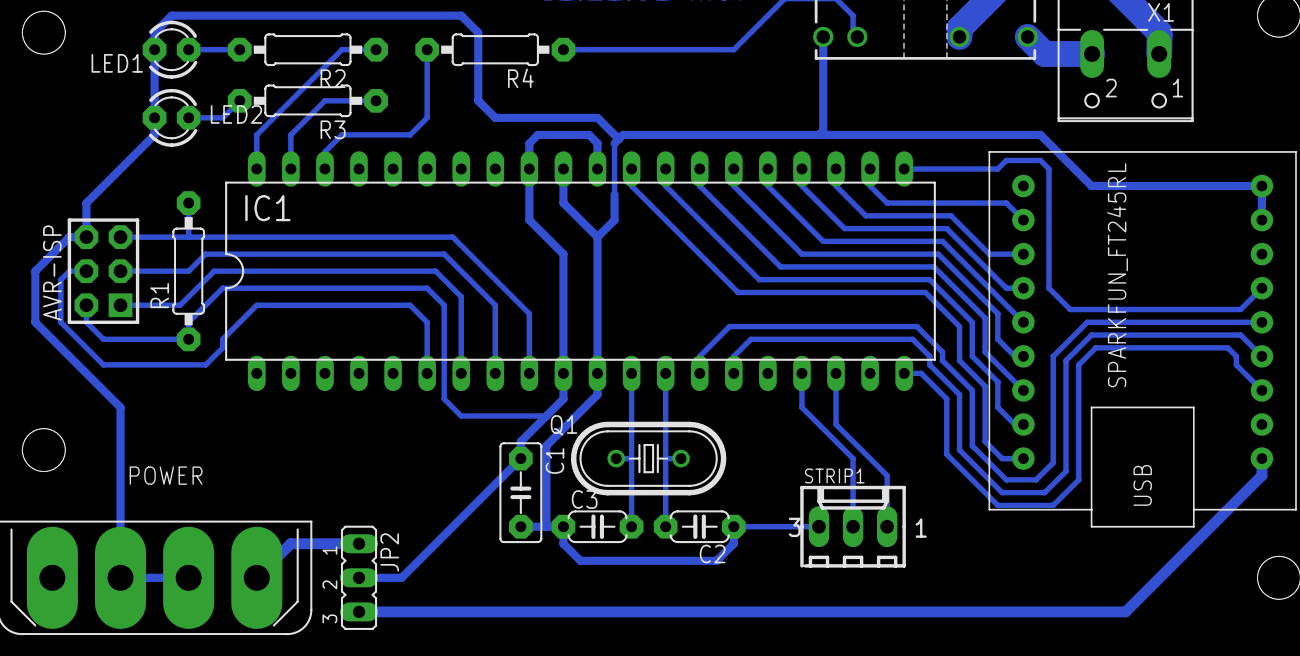
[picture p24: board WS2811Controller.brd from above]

Board: 2 copper layers, 18 parts (0 on the bottom side), 32 nets.

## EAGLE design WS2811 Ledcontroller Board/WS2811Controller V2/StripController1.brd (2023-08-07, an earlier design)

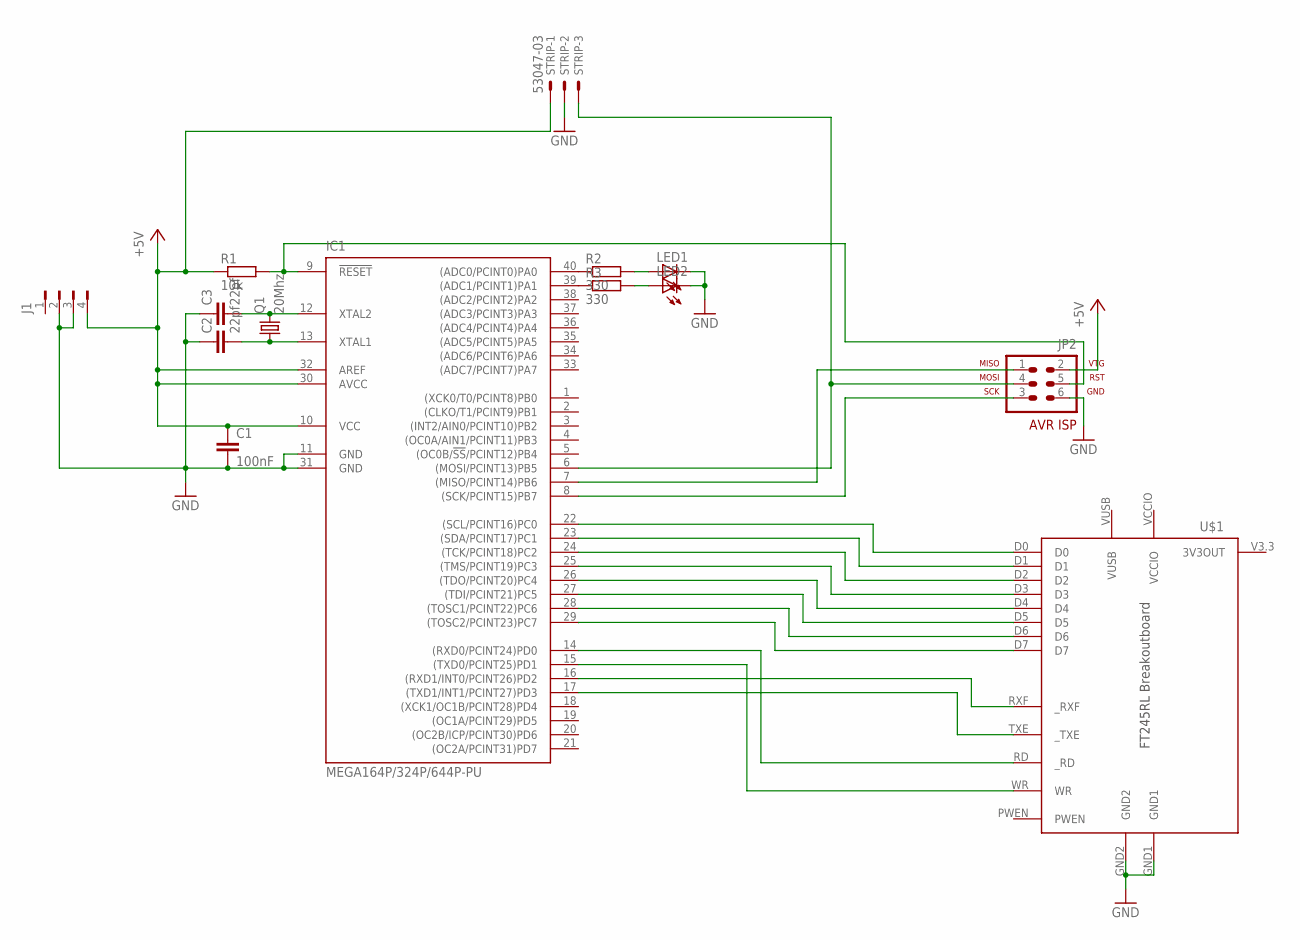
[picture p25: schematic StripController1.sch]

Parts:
C1: 100nF; C050-030X075
C2, C3: 22pf; C050-024X044
IC1: MEGA164P/324P/644P-PU; DIL40
J1: FLOPPY-4
JP2: AVR-ISP-6
LED1, LED2: LED3MM
Q1: 20Mhz; HC49U70
R1: 10k; 0207/10
R2, R3: 330; 0207/10
STRIP: 53047-03
U$1: FT245RL_BREAKOUTBOARD; SPARKFUN_FT245RL_BOARD

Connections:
+5V: C1.1, IC1.10 (VCC), IC1.30 (AVCC), IC1.32 (AREF), J1.4, JP2.2, R1.1, STRIP.1
GND: C1.2, C2.1, C3.1, IC1.11 (GND), IC1.31 (GND), J1.2, J1.3, JP2.6, LED1.K (C), LED2.K (C), STRIP.2, U$1.GND1, U$1.GND2
unnamed: IC1.8 ((SCK/PCINT15)PB7), JP2.3
unnamed: IC1.7 ((MISO/PCINT14)PB6), JP2.1
unnamed: IC1.40 ((ADC0/PCINT0)PA0), R2.1
unnamed: IC1.9 (!RESET), JP2.5, R1.2
unnamed: IC1.6 ((MOSI/PCINT13)PB5), JP2.4, STRIP.3
unnamed: IC1.39 ((ADC1/PCINT1)PA1), R3.1
unnamed: IC1.22 ((SCL/PCINT16)PC0), U$1.D0
unnamed: C2.2, IC1.13 (XTAL1), Q1.1
unnamed: C3.2, IC1.12 (XTAL2), Q1.2
unnamed: IC1.23 ((SDA/PCINT17)PC1), U$1.D1
unnamed: IC1.24 ((TCK/PCINT18)PC2), U$1.D2
unnamed: IC1.25 ((TMS/PCINT19)PC3), U$1.D3
unnamed: IC1.26 ((TDO/PCINT20)PC4), U$1.D4
unnamed: IC1.27 ((TDI/PCINT21)PC5), U$1.D5
unnamed: IC1.28 ((TOSC1/PCINT22)PC6), U$1.D6
unnamed: IC1.29 ((TOSC2/PCINT23)PC7), U$1.D7
unnamed: IC1.17 ((TXD1/INT1/PCINT27)PD3), U$1.TXE (_TXE)
unnamed: IC1.16 ((RXD1/INT0/PCINT26)PD2), U$1.RXF (_RXF)
unnamed: IC1.14 ((RXD0/PCINT24)PD0), U$1.RD (_RD)
unnamed: IC1.15 ((TXD0/PCINT25)PD1), U$1.WR
unnamed: LED1.A, R2.2
unnamed: LED2.A, R3.2
VCCIO: U$1.VCCIO

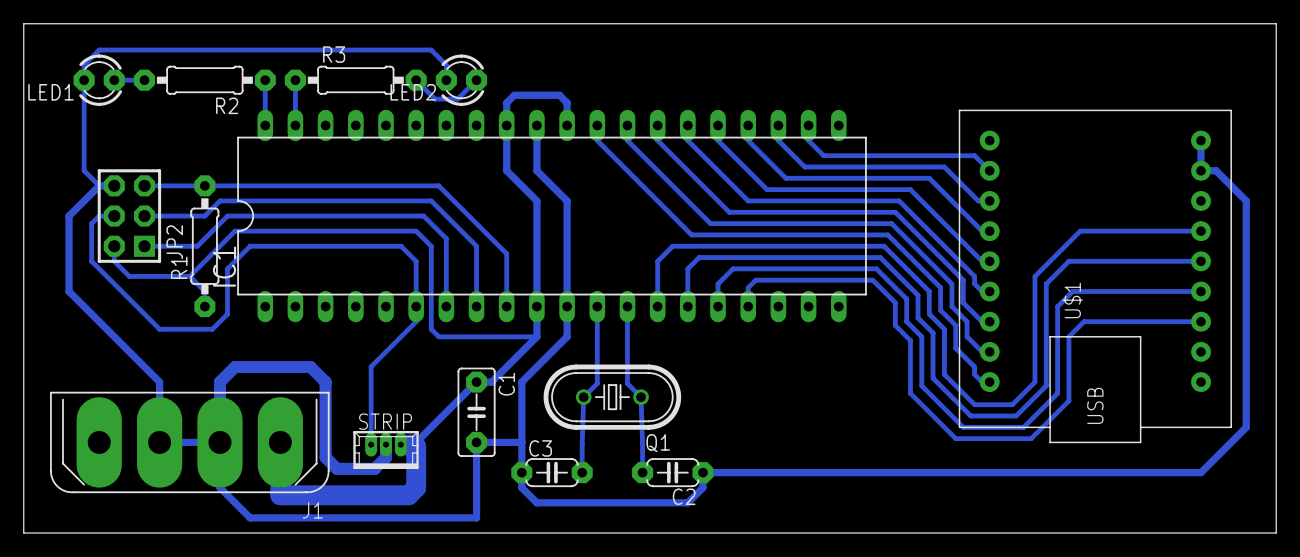
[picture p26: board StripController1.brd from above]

Board: 2 copper layers, 105.4 x 42.9 mm, 14 parts (0 on the bottom side), 24 nets.

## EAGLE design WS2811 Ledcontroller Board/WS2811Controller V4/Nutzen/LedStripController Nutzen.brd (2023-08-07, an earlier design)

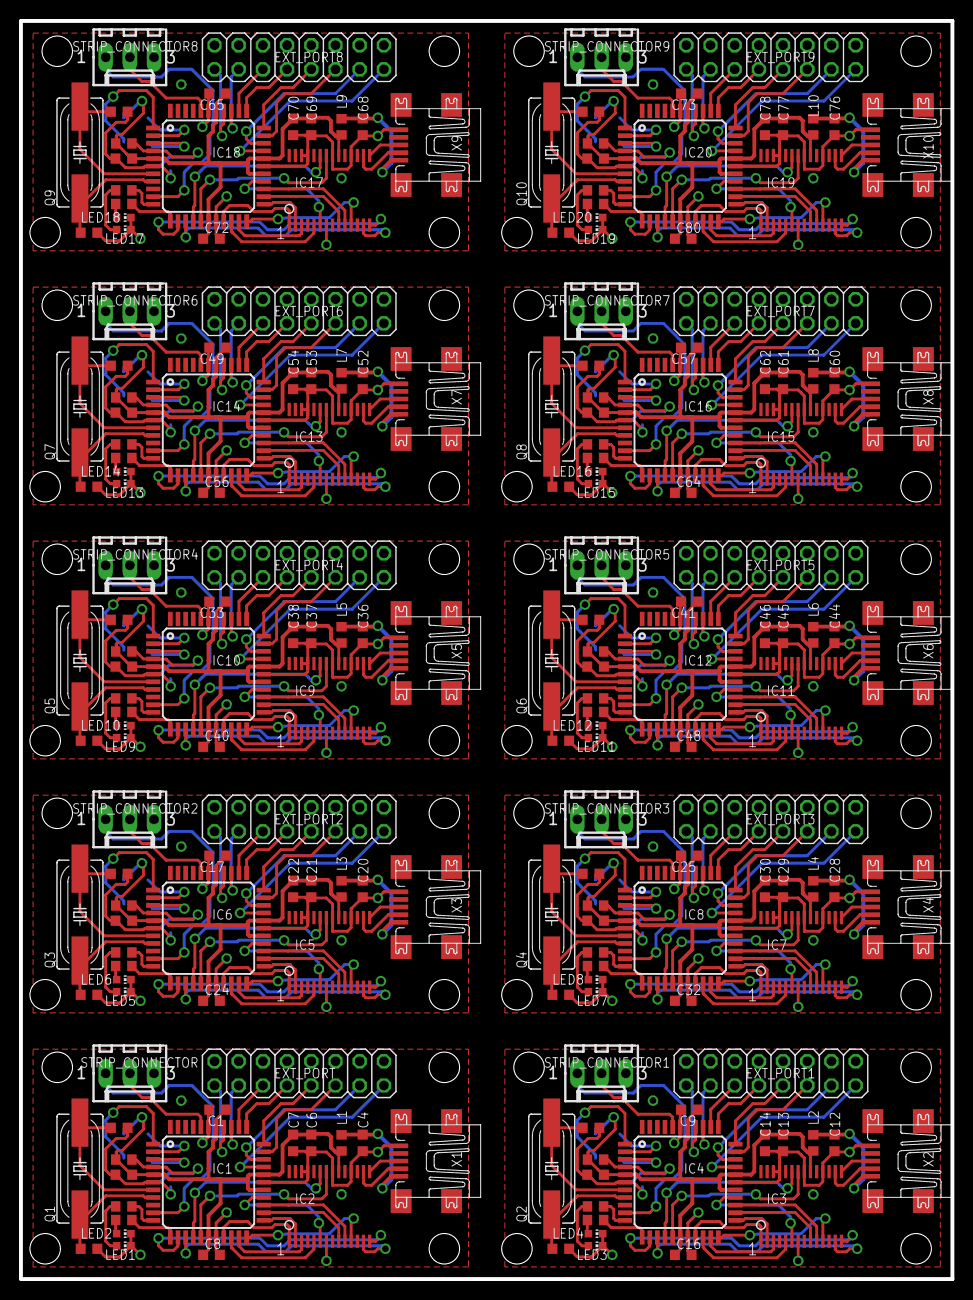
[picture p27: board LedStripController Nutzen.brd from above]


Board: 2 copper layers, 97.8 x 132.1 mm, 265 parts (60 on the bottom side), 370 nets.

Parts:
+5V, +5V1, +5V2, +5V3, +5V4, +5V5, +5V6, +5V7, +5V8, +5V9: TP19R
C1, C5, C6, C8, C9, C13, C15, C16, C17, C21, C23, C24, C25, C29, C31, C32, C33, C37, C39, C40, C41, C45, C47, C48, C49, C53, C55, C56, C57, C61, C63, C64, C65, C69, C71, C72, C73, C77, C79, C80: 100nF; C0603K
C2, C3, C10, C11, C18, C19, C26, C27, C34, C35, C42, C43, C50, C51, C58, C59, C66, C67, C74, C75: 22pf; C0603K
C4, C12, C20, C28, C36, C44, C52, C60, C68, C76: 10n; C0603K
C7, C14, C22, C30, C38, C46, C54, C62, C70, C78: 10uf; C0603K
E$1, E$2, E$3, E$4, E$5: DOUBLE_LIZARD_SMALL
EXT_PORT, EXT_PORT1, EXT_PORT2, EXT_PORT3, EXT_PORT4, EXT_PORT5, EXT_PORT6, EXT_PORT7, EXT_PORT8, EXT_PORT9: 2X08
GND, GND1, GND2, GND3, GND4, GND5, GND6, GND7, GND8, GND9: TP19R
IC1, IC4, IC6, IC8, IC10, IC12, IC14, IC16, IC18, IC20: MEGA1284; TQFP44
IC2, IC3, IC5, IC7, IC9, IC11, IC13, IC15, IC17, IC19: FT245RL; SSOP28DB
L1, L2, L3, L4, L5, L6, L7, L8, L9, L10: 1.5A/307; R0603
LED1, LED2, LED3, LED4, LED5, LED6, LED7, LED8, LED9, LED10, LED11, LED12, LED13, LED14, LED15, LED16, LED17, LED18, LED19, LED20: CHIP-LED0603
MISO, MISO1, MISO2, MISO3, MISO4, MISO5, MISO6, MISO7, MISO8, MISO9: TP19R
MOSI, MOSI1, MOSI2, MOSI3, MOSI4, MOSI5, MOSI6, MOSI7, MOSI8, MOSI9: TP19R
Q1, Q2, Q3, Q4, Q5, Q6, Q7, Q8, Q9, Q10: 20Mhz; SM49
R1, R4, R7, R10, R13, R16, R19, R22, R25, R28: 10k; R0603
R2, R3, R5, R6, R8, R9, R11, R12, R14, R15, R17, R18, R20, R21, R23, R24, R26, R27, R29, R30: 330; R0603
RST, RST1, RST2, RST3, RST4, RST5, RST6, RST7, RST8, RST9: TP19R
SCK, SCK1, SCK2, SCK3, SCK4, SCK5, SCK6, SCK7, SCK8, SCK9: TP19R
STRIP_CONNECTOR, STRIP_CONNECTOR1, STRIP_CONNECTOR2, STRIP_CONNECTOR3, STRIP_CONNECTOR4, STRIP_CONNECTOR5, STRIP_CONNECTOR6, STRIP_CONNECTOR7, STRIP_CONNECTOR8, STRIP_CONNECTOR9: 6410-03
X1, X2, X3, X4, X5, X6, X7, X8, X9, X10: MINI-USB-UX60A-MB-5ST; UX60A-MB-5ST

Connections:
+5V: +5V.TP, C1.1, C5.1, C6.1, C7.1, C8.1, IC1.5, IC1.17, IC1.27, IC1.29, IC1.38, IC2.20, L1.2, R1.1
+5V1: +5V1.TP, C9.1, C13.1, C14.1, C15.1, C16.1, IC3.20, IC4.5, IC4.17, IC4.27, IC4.29, IC4.38, L2.2, R4.1
+5V2: +5V2.TP, C17.1, C21.1, C22.1, C23.1, C24.1, IC5.20, IC6.5, IC6.17, IC6.27, IC6.29, IC6.38, L3.2, R7.1
+5V3: +5V3.TP, C25.1, C29.1, C30.1, C31.1, C32.1, IC7.20, IC8.5, IC8.17, IC8.27, IC8.29, IC8.38, L4.2, R10.1
+5V4: +5V4.TP, C33.1, C37.1, C38.1, C39.1, C40.1, IC9.20, IC10.5, IC10.17, IC10.27, IC10.29, IC10.38, L5.2, R13.1
+5V5: +5V5.TP, C41.1, C45.1, C46.1, C47.1, C48.1, IC11.20, IC12.5, IC12.17, IC12.27, IC12.29, IC12.38, L6.2, R16.1
+5V6: +5V6.TP, C49.1, C53.1, C54.1, C55.1, C56.1, IC13.20, IC14.5, IC14.17, IC14.27, IC14.29, IC14.38, L7.2, R19.1
+5V7: +5V7.TP, C57.1, C61.1, C62.1, C63.1, C64.1, IC15.20, IC16.5, IC16.17, IC16.27, IC16.29, IC16.38, L8.2, R22.1
+5V8: +5V8.TP, C65.1, C69.1, C70.1, C71.1, C72.1, IC17.20, IC18.5, IC18.17, IC18.27, IC18.29, IC18.38, L9.2, R25.1
+5V9: +5V9.TP, C73.1, C77.1, C78.1, C79.1, C80.1, IC19.20, IC20.5, IC20.17, IC20.27, IC20.29, IC20.38, L10.2, R28.1
CLOCK: IC1.40, STRIP_CONNECTOR.2
CLOCK1: IC4.40, STRIP_CONNECTOR1.2
CLOCK2: IC6.40, STRIP_CONNECTOR2.2
CLOCK3: IC8.40, STRIP_CONNECTOR3.2
CLOCK4: IC10.40, STRIP_CONNECTOR4.2
CLOCK5: IC12.40, STRIP_CONNECTOR5.2
CLOCK6: IC14.40, STRIP_CONNECTOR6.2
CLOCK7: IC16.40, STRIP_CONNECTOR7.2
CLOCK8: IC18.40, STRIP_CONNECTOR8.2
CLOCK9: IC20.40, STRIP_CONNECTOR9.2
D0: IC1.19, IC2.1
D1: IC1.20, IC2.5
D2: IC1.21, IC2.3
D3: IC1.22, IC2.11
D4: IC1.23, IC2.2
D5: IC1.24, IC2.9
D6: IC1.25, IC2.10
D7: IC1.26, IC2.6
D8: IC3.1, IC4.19
D9: IC3.5, IC4.20
D10: IC3.3, IC4.21
D11: IC3.11, IC4.22
D12: IC3.2, IC4.23
D13: IC3.10, IC4.25
D14: IC3.6, IC4.26
D15: IC3.9, IC4.24
D16: IC5.1, IC6.19
D17: IC5.5, IC6.20
D18: IC5.3, IC6.21
D19: IC5.11, IC6.22
D20: IC5.2, IC6.23
D21: IC5.10, IC6.25
D22: IC5.6, IC6.26
D23: IC5.9, IC6.24
D24: IC7.1, IC8.19
D25: IC7.5, IC8.20
D26: IC7.3, IC8.21
D27: IC7.11, IC8.22
D28: IC7.2, IC8.23
D29: IC7.10, IC8.25
D30: IC7.6, IC8.26
D31: IC7.9, IC8.24
D32: IC9.1, IC10.19
D33: IC9.5, IC10.20
D34: IC9.3, IC10.21
D35: IC9.11, IC10.22
D36: IC9.2, IC10.23
D37: IC9.10, IC10.25
D38: IC9.6, IC10.26
D39: IC9.9, IC10.24
D40: IC11.1, IC12.19
D41: IC11.5, IC12.20
D42: IC11.3, IC12.21
D43: IC11.11, IC12.22
D44: IC11.2, IC12.23
D45: IC11.10, IC12.25
D46: IC11.6, IC12.26
D47: IC11.9, IC12.24
D48: IC13.1, IC14.19
D49: IC13.5, IC14.20
D50: IC13.3, IC14.21
D51: IC13.11, IC14.22
D52: IC13.2, IC14.23
D53: IC13.10, IC14.25
D54: IC13.6, IC14.26
D55: IC13.9, IC14.24
D56: IC15.1, IC16.19
D57: IC15.5, IC16.20
D58: IC15.3, IC16.21
D59: IC15.11, IC16.22
D60: IC15.2, IC16.23
D61: IC15.10, IC16.25
D62: IC15.6, IC16.26
D63: IC15.9, IC16.24
D64: IC17.1, IC18.19
D65: IC17.5, IC18.20
D66: IC17.3, IC18.21
D67: IC17.11, IC18.22
D68: IC17.2, IC18.23
D69: IC17.10, IC18.25
D70: IC17.6, IC18.26
D71: IC17.9, IC18.24
D72: IC19.1, IC20.19
D73: IC19.5, IC20.20
D74: IC19.3, IC20.21
D75: IC19.11, IC20.22
D76: IC19.2, IC20.23
D77: IC19.10, IC20.25
D78: IC19.6, IC20.26
D79: IC19.9, IC20.24
D+: IC2.15, X1.3
D+1: IC3.15, X2.3
D+2: IC5.15, X3.3
D+3: IC7.15, X4.3
D+4: IC9.15, X5.3
D+5: IC11.15, X6.3
D+6: IC13.15, X7.3
D+7: IC15.15, X8.3
D+8: IC17.15, X9.3
D+9: IC19.15, X10.3
D-: IC2.16, X1.2
D-1: IC3.16, X2.2
D-2: IC5.16, X3.2
D-3: IC7.16, X4.2
D-4: IC9.16, X5.2
D-5: IC11.16, X6.2
D-6: IC13.16, X7.2
D-7: IC15.16, X8.2
D-8: IC17.16, X9.2
D-9: IC19.16, X10.2
DATA: IC1.10, STRIP_CONNECTOR.1
DATA1: IC4.10, STRIP_CONNECTOR1.1
DATA2: IC6.10, STRIP_CONNECTOR2.1
DATA3: IC8.10, STRIP_CONNECTOR3.1
DATA4: IC10.10, STRIP_CONNECTOR4.1
DATA5: IC12.10, STRIP_CONNECTOR5.1
DATA6: IC14.10, STRIP_CONNECTOR6.1
DATA7: IC16.10, STRIP_CONNECTOR7.1
DATA8: IC18.10, STRIP_CONNECTOR8.1
DATA9: IC20.10, STRIP_CONNECTOR9.1
GND: C1.2, C2.1, C3.1, C4.2, C5.2, C6.2, C7.2, C8.2, EXT_PORT.2, EXT_PORT.4, EXT_PORT.6, EXT_PORT.8, EXT_PORT.10, EXT_PORT.12, EXT_PORT.14, EXT_PORT.16, GND.TP, IC1.6, IC1.18, IC1.28, IC1.39, IC2.7, IC2.18, IC2.21, IC2.25, IC2.26, LED1.C, LED2.C, STRIP_CONNECTOR.3, X1.5
GND1: C9.2, C10.1, C11.1, C12.2, C13.2, C14.2, C15.2, C16.2, EXT_PORT1.2, EXT_PORT1.4, EXT_PORT1.6, EXT_PORT1.8, EXT_PORT1.10, EXT_PORT1.12, EXT_PORT1.14, EXT_PORT1.16, GND1.TP, IC3.7, IC3.18, IC3.21, IC3.25, IC3.26, IC4.6, IC4.18, IC4.28, IC4.39, LED3.C, LED4.C, STRIP_CONNECTOR1.3, X2.5
GND2: C17.2, C18.1, C19.1, C20.2, C21.2, C22.2, C23.2, C24.2, EXT_PORT2.2, EXT_PORT2.4, EXT_PORT2.6, EXT_PORT2.8, EXT_PORT2.10, EXT_PORT2.12, EXT_PORT2.14, EXT_PORT2.16, GND2.TP, IC5.7, IC5.18, IC5.21, IC5.25, IC5.26, IC6.6, IC6.18, IC6.28, IC6.39, LED5.C, LED6.C, STRIP_CONNECTOR2.3, X3.5
GND3: C25.2, C26.1, C27.1, C28.2, C29.2, C30.2, C31.2, C32.2, EXT_PORT3.2, EXT_PORT3.4, EXT_PORT3.6, EXT_PORT3.8, EXT_PORT3.10, EXT_PORT3.12, EXT_PORT3.14, EXT_PORT3.16, GND3.TP, IC7.7, IC7.18, IC7.21, IC7.25, IC7.26, IC8.6, IC8.18, IC8.28, IC8.39, LED7.C, LED8.C, STRIP_CONNECTOR3.3, X4.5
GND4: C33.2, C34.1, C35.1, C36.2, C37.2, C38.2, C39.2, C40.2, EXT_PORT4.2, EXT_PORT4.4, EXT_PORT4.6, EXT_PORT4.8, EXT_PORT4.10, EXT_PORT4.12, EXT_PORT4.14, EXT_PORT4.16, GND4.TP, IC9.7, IC9.18, IC9.21, IC9.25, IC9.26, IC10.6, IC10.18, IC10.28, IC10.39, LED9.C, LED10.C, STRIP_CONNECTOR4.3, X5.5
GND5: C41.2, C42.1, C43.1, C44.2, C45.2, C46.2, C47.2, C48.2, EXT_PORT5.2, EXT_PORT5.4, EXT_PORT5.6, EXT_PORT5.8, EXT_PORT5.10, EXT_PORT5.12, EXT_PORT5.14, EXT_PORT5.16, GND5.TP, IC11.7, IC11.18, IC11.21, IC11.25, IC11.26, IC12.6, IC12.18, IC12.28, IC12.39, LED11.C, LED12.C, STRIP_CONNECTOR5.3, X6.5
GND6: C49.2, C50.1, C51.1, C52.2, C53.2, C54.2, C55.2, C56.2, EXT_PORT6.2, EXT_PORT6.4, EXT_PORT6.6, EXT_PORT6.8, EXT_PORT6.10, EXT_PORT6.12, EXT_PORT6.14, EXT_PORT6.16, GND6.TP, IC13.7, IC13.18, IC13.21, IC13.25, IC13.26, IC14.6, IC14.18, IC14.28, IC14.39, LED13.C, LED14.C, STRIP_CONNECTOR6.3, X7.5
GND7: C57.2, C58.1, C59.1, C60.2, C61.2, C62.2, C63.2, C64.2, EXT_PORT7.2, EXT_PORT7.4, EXT_PORT7.6, EXT_PORT7.8, EXT_PORT7.10, EXT_PORT7.12, EXT_PORT7.14, EXT_PORT7.16, GND7.TP, IC15.7, IC15.18, IC15.21, IC15.25, IC15.26, IC16.6, IC16.18, IC16.28, IC16.39, LED15.C, LED16.C, STRIP_CONNECTOR7.3, X8.5
GND8: C65.2, C66.1, C67.1, C68.2, C69.2, C70.2, C71.2, C72.2, EXT_PORT8.2, EXT_PORT8.4, EXT_PORT8.6, EXT_PORT8.8, EXT_PORT8.10, EXT_PORT8.12, EXT_PORT8.14, EXT_PORT8.16, GND8.TP, IC17.7, IC17.18, IC17.21, IC17.25, IC17.26, IC18.6, IC18.18, IC18.28, IC18.39, LED17.C, LED18.C, STRIP_CONNECTOR8.3, X9.5
GND9: C73.2, C74.1, C75.1, C76.2, C77.2, C78.2, C79.2, C80.2, EXT_PORT9.2, EXT_PORT9.4, EXT_PORT9.6, EXT_PORT9.8, EXT_PORT9.10, EXT_PORT9.12, EXT_PORT9.14, EXT_PORT9.16, GND9.TP, IC19.7, IC19.18, IC19.21, IC19.25, IC19.26, IC20.6, IC20.18, IC20.28, IC20.39, LED19.C, LED20.C, STRIP_CONNECTOR9.3, X10.5
MISO: IC1.2, MISO.TP
MISO1: IC4.2, MISO1.TP
MISO2: IC6.2, MISO2.TP
MISO3: IC8.2, MISO3.TP
MISO4: IC10.2, MISO4.TP
MISO5: IC12.2, MISO5.TP
MISO6: IC14.2, MISO6.TP
MISO7: IC16.2, MISO7.TP
MISO8: IC18.2, MISO8.TP
MISO9: IC20.2, MISO9.TP
MOSI: IC1.1, MOSI.TP
MOSI1: IC4.1, MOSI1.TP
MOSI2: IC6.1, MOSI2.TP
MOSI3: IC8.1, MOSI3.TP
MOSI4: IC10.1, MOSI4.TP
MOSI5: IC12.1, MOSI5.TP
MOSI6: IC14.1, MOSI6.TP
MOSI7: IC16.1, MOSI7.TP
MOSI8: IC18.1, MOSI8.TP
MOSI9: IC20.1, MOSI9.TP
unnamed: EXT_PORT.15, IC1.30
unnamed: EXT_PORT.13, IC1.31
unnamed: IC1.11, R2.1
unnamed: EXT_PORT.11, IC1.32
unnamed: EXT_PORT.9, IC1.33
unnamed: IC1.12, R3.1
unnamed: EXT_PORT.7, IC1.34
unnamed: C2.2, IC1.8, Q1.1
unnamed: C3.2, IC1.7, Q1.2
unnamed: EXT_PORT.5, IC1.35
unnamed: EXT_PORT.3, IC1.36
unnamed: C10.2, IC4.8, Q2.1
unnamed: EXT_PORT.1, IC1.37
unnamed: C11.2, IC4.7, Q2.2
unnamed: LED3.A, R5.2
unnamed: LED4.A, R6.2
unnamed: EXT_PORT1.15, IC4.30
unnamed: EXT_PORT1.13, IC4.31
unnamed: EXT_PORT1.11, IC4.32
unnamed: EXT_PORT1.9, IC4.33
unnamed: LED1.A, R2.2
unnamed: LED2.A, R3.2
unnamed: EXT_PORT1.7, IC4.34
unnamed: EXT_PORT1.5, IC4.35
unnamed: EXT_PORT1.3, IC4.36
unnamed: EXT_PORT1.1, IC4.37
unnamed: IC4.11, R5.1
unnamed: IC4.12, R6.1
unnamed: C18.2, IC6.8, Q3.1
unnamed: C19.2, IC6.7, Q3.2
unnamed: LED5.A, R8.2
unnamed: LED6.A, R9.2
unnamed: EXT_PORT2.15, IC6.30
unnamed: EXT_PORT2.13, IC6.31
unnamed: EXT_PORT2.11, IC6.32
unnamed: EXT_PORT2.9, IC6.33
unnamed: EXT_PORT2.7, IC6.34
unnamed: EXT_PORT2.5, IC6.35
unnamed: EXT_PORT2.3, IC6.36
unnamed: EXT_PORT2.1, IC6.37
unnamed: IC6.11, R8.1
unnamed: IC6.12, R9.1
unnamed: C26.2, IC8.8, Q4.1
unnamed: C27.2, IC8.7, Q4.2
unnamed: LED7.A, R11.2
unnamed: LED8.A, R12.2
unnamed: EXT_PORT3.15, IC8.30
unnamed: EXT_PORT3.13, IC8.31
unnamed: EXT_PORT3.11, IC8.32
unnamed: EXT_PORT3.9, IC8.33
unnamed: EXT_PORT3.7, IC8.34
unnamed: EXT_PORT3.5, IC8.35
unnamed: EXT_PORT3.3, IC8.36
unnamed: EXT_PORT3.1, IC8.37
unnamed: IC8.11, R11.1
unnamed: IC8.12, R12.1
unnamed: C34.2, IC10.8, Q5.1
unnamed: C35.2, IC10.7, Q5.2
unnamed: LED9.A, R14.2
unnamed: LED10.A, R15.2
unnamed: EXT_PORT4.15, IC10.30
unnamed: EXT_PORT4.13, IC10.31
unnamed: EXT_PORT4.11, IC10.32
unnamed: EXT_PORT4.9, IC10.33
unnamed: EXT_PORT4.7, IC10.34
unnamed: EXT_PORT4.5, IC10.35
unnamed: EXT_PORT4.3, IC10.36
unnamed: EXT_PORT4.1, IC10.37
unnamed: IC10.11, R14.1
unnamed: IC10.12, R15.1
unnamed: C42.2, IC12.8, Q6.1
unnamed: C43.2, IC12.7, Q6.2
unnamed: LED11.A, R17.2
unnamed: LED12.A, R18.2
unnamed: EXT_PORT5.15, IC12.30
unnamed: EXT_PORT5.13, IC12.31
unnamed: EXT_PORT5.11, IC12.32
unnamed: EXT_PORT5.9, IC12.33
unnamed: EXT_PORT5.7, IC12.34
unnamed: EXT_PORT5.5, IC12.35
unnamed: EXT_PORT5.3, IC12.36
unnamed: EXT_PORT5.1, IC12.37
unnamed: IC12.11, R17.1
unnamed: IC12.12, R18.1
unnamed: C50.2, IC14.8, Q7.1
unnamed: C51.2, IC14.7, Q7.2
unnamed: LED13.A, R20.2
unnamed: LED14.A, R21.2
unnamed: EXT_PORT6.15, IC14.30
unnamed: EXT_PORT6.13, IC14.31
unnamed: EXT_PORT6.11, IC14.32
unnamed: EXT_PORT6.9, IC14.33
unnamed: EXT_PORT6.7, IC14.34
unnamed: EXT_PORT6.5, IC14.35
unnamed: EXT_PORT6.3, IC14.36
unnamed: EXT_PORT6.1, IC14.37
unnamed: IC14.11, R20.1
unnamed: IC14.12, R21.1
unnamed: C58.2, IC16.8, Q8.1
unnamed: C59.2, IC16.7, Q8.2
unnamed: LED15.A, R23.2
unnamed: LED16.A, R24.2
unnamed: EXT_PORT7.15, IC16.30
unnamed: EXT_PORT7.13, IC16.31
unnamed: EXT_PORT7.11, IC16.32
unnamed: EXT_PORT7.9, IC16.33
unnamed: EXT_PORT7.7, IC16.34
unnamed: EXT_PORT7.5, IC16.35
unnamed: EXT_PORT7.3, IC16.36
unnamed: EXT_PORT7.1, IC16.37
unnamed: IC16.11, R23.1
unnamed: IC16.12, R24.1
unnamed: C66.2, IC18.8, Q9.1
unnamed: C67.2, IC18.7, Q9.2
unnamed: LED17.A, R26.2
unnamed: LED18.A, R27.2
unnamed: EXT_PORT8.15, IC18.30
unnamed: EXT_PORT8.13, IC18.31
unnamed: EXT_PORT8.11, IC18.32
unnamed: EXT_PORT8.9, IC18.33
unnamed: EXT_PORT8.7, IC18.34
unnamed: EXT_PORT8.5, IC18.35
unnamed: EXT_PORT8.3, IC18.36
unnamed: EXT_PORT8.1, IC18.37
unnamed: IC18.11, R26.1
unnamed: IC18.12, R27.1
unnamed: C74.2, IC20.8, Q10.1
unnamed: C75.2, IC20.7, Q10.2
unnamed: LED19.A, R29.2
unnamed: LED20.A, R30.2
unnamed: EXT_PORT9.15, IC20.30
unnamed: EXT_PORT9.13, IC20.31
unnamed: EXT_PORT9.11, IC20.32
unnamed: EXT_PORT9.9, IC20.33
unnamed: EXT_PORT9.7, IC20.34
unnamed: EXT_PORT9.5, IC20.35
unnamed: EXT_PORT9.3, IC20.36
unnamed: EXT_PORT9.1, IC20.37
unnamed: IC20.11, R29.1
unnamed: IC20.12, R30.1
RD: IC1.14, IC2.13
RD1: IC3.13, IC4.14
RD2: IC5.13, IC6.14
RD3: IC7.13, IC8.14
RD4: IC9.13, IC10.14
RD5: IC11.13, IC12.14
RD6: IC13.13, IC14.14
RD7: IC15.13, IC16.14
RD8: IC17.13, IC18.14
RD9: IC19.13, IC20.14
RST: IC1.4, R1.2, RST.TP
RST1: IC4.4, R4.2, RST1.TP
RST2: IC6.4, R7.2, RST2.TP
RST3: IC8.4, R10.2, RST3.TP
RST4: IC10.4, R13.2, RST4.TP
RST5: IC12.4, R16.2, RST5.TP
RST6: IC14.4, R19.2, RST6.TP
RST7: IC16.4, R22.2, RST7.TP
RST8: IC18.4, R25.2, RST8.TP
RST9: IC20.4, R28.2, RST9.TP
RXF: IC1.15, IC2.23
RXF1: IC3.23, IC4.15
RXF2: IC5.23, IC6.15
RXF3: IC7.23, IC8.15
RXF4: IC9.23, IC10.15
RXF5: IC11.23, IC12.15
RXF6: IC13.23, IC14.15
RXF7: IC15.23, IC16.15
RXF8: IC17.23, IC18.15
RXF9: IC19.23, IC20.15
SCK: IC1.3, SCK.TP
SCK1: IC4.3, SCK1.TP
SCK2: IC6.3, SCK2.TP
SCK3: IC8.3, SCK3.TP
SCK4: IC10.3, SCK4.TP
SCK5: IC12.3, SCK5.TP
SCK6: IC14.3, SCK6.TP
SCK7: IC16.3, SCK7.TP
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

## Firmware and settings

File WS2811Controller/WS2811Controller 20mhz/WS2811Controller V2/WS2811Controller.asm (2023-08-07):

 .include "m644Pdef.inc" 
 .LISTMAC
 
 .equ VersionHigh=1
 .equ VersionLow=1
 
 ;********************************************************
 ;** Constants
 ;********************************************************

 .equ DataBufferSize=SRAM_SIZE-64

 ;********************************************************
 ;** Ports
 ;********************************************************

 ;FT245RL
 ;Use ports with adresses<0x20 for the FT245 to allow for most efficient communication
 .EQU FT245_DataPort = PORTC
 .equ FT245_DataPin = PINC
 .equ FT245_DataDDR = DDRC

 .equ FT245_StatusPin=PIND
 .equ FT245_StatusPort=PORTD
 .equ FT245_StatusDDR=DDRD

 .equ FT245_TXEBit=6
 .equ FT245_RXFBit=1
 .equ FT245_WRBit=0
 .equ FT245_RDBit=7

 ;Leds
 .equ Led_DDR=DDRB
 .equ Led_Port=PORTB
 .equ Led_Yellow_Bit=0
 .equ Led_Red_Bit=1

 ;WS2811 Data Line
 .equ WS2811_DDR=DDRD
 .equ WS2811_Port=PORTD
 .equ WS2811_Bit=3;

 ;ExtPort
 .equ Ext_DDR=DDRA
 .equ Ext_Port=PORTA



 ;********************************************************
 ;** Registers
 ;********************************************************

 ;R17 is RTemp (defined in macros.inc)

 .def RBufferLoopCounter=R24
 .def RBufferLoopCounterHigh=R25
 
 .def RCommandByte=R18
 
 .def RData=R0
 

 .def RL2=r20
.def RL1=r16
.def RL0=r19

 ;*******************************************************
 ;** Calculated constants
 ;*******************************************************
 
 

 ;*******************************************************
 ;** Macros
 ;*******************************************************
 

 .include "macros.inc" 
 .include "ProjectMacros.inc"

;*********************************************
;** Init
;*********************************************
.CSEG
Init:	
	cli						; no interrupts allowed
	ldi	RTemp, low (RamEnd)	; initialize stack
	out	SPL, RTemp
	ldi	RTemp, high(RamEnd)
	out	SPH, RTemp

  ;Set IO direction for FT245 data port (input)
  FT245_SetInput

  ;Set IO Directtion for FT245 status connectors
  SetPortBit FT245_StatusDDR,FT245_WRBit
  SetPortBit FT245_StatusDDR,FT245_RDBit
  ClearPortBit FT245_StatusDDR,FT245_RxfBit
  ClearPortBit FT245_StatusDDR,FT245_TXEBit

  ;Set Rd and WR to initial values
  SetPortBit FT245_StatusPort,FT245_RDBit
  SetPortBit FT245_StatusPort,FT245_WRBit

  ;Empty input buffer
  FT245_ClearInputBuffer
  
  ;Init ExtPort
  WritePortValue Ext_DDR,0xff
  WritePortValue Ext_Port,0

  ;Set led port bits to output & turn leds off
  SetPortBit Led_DDR,Led_Yellow_Bit
  SetPortBit Led_DDR,Led_Red_Bit
  ClearPortBit Led_Port,Led_Yellow_Bit
  ClearPortBit Led_Port,Led_Red_Bit

  ;Set IO direction to output for WS2811 connector
  SetPortBit WS2811_DDR,WS2811_Bit
  ClearPortBit WS2811_Port,WS2811_Bit

  
  Main:
	 //First command byte is received by the bootloader
	 RCall Processcommand

     FT245_WaitForRead_PayLoad LedBothBlink
	 
	 FT245_ReadByte RCommandByte

  rjmp Main




  ProcessCommand:
    subi RCommandByte,MinCommandByte
	cpi RCommandByte,(MaxCommandByte-MinCommandByte+1)
	brsh ProcessCommand_NoValidCommand
	ldi ZL,low(ProcessCommandJumps);
	ldi ZH,high(ProcessCommandJumps);
	add ZL,RCommandByte
	ldi RCommandByte,0
	adc ZH,RCommandByte
	ijmp

  ProcessCommand_NoValidCommand:
  rjmp UnknownCommand

  ;Use RJMP for the process command jumps. If the JMP statement has to be used to accomodate longer jumps, 
  ;the added command byte value has to be shifted left one position to support the JMP statement (4 byte vs 2 bytes) 
  ;and the calculation for MaxCommandByte has to be adjusted as well.
  ;The procedures called in the following section must all end with Ret
  ProcessCommandJumps:   
    rjmp UnknownCommand		;A
	rjmp UnknownCommand		;B
    rjmp ClearDataBuffer	;C
    rjmp UnknownCommand		;D
    rjmp ExtPort			;E
    rjmp UnknownCommand		;F
    rjmp UnknownCommand		;G
    rjmp UnknownCommand		;H
    rjmp UnknownCommand		;I
    rjmp UnknownCommand		;J
    rjmp UnknownCommand		;K
    rjmp UnknownCommand		;L
    rjmp UnknownCommand		;M
    rjmp UnknownCommand		;N
    rjmp OutputData			;O
    rjmp UnknownCommand		;P
    rjmp UnknownCommand		;Q
    rjmp ReceiveData		;R
    rjmp UnknownCommand		;S
    rjmp UnknownCommand		;T
    rjmp UnknownCommand		;U
    rjmp SendVersion		;V
    rjmp UnknownCommand		;W
    rjmp UnknownCommand		;X
    rjmp UnknownCommand		;Y
    rjmp EnterBootLoader		;Z - Reserved for bootloader
    rjmp UnknownCommand		;Just to be sure

  ;The folowing label must follow immediately after the jump statements. It is used to detemine the max command number  
  ProcessCommandJumpsEnd:
  .equ MinCommandByte = 'A'
  .equ MaxCommandByte = 'Z'


;Is called when a unknown command byte has been received
UnknownCommand:
  FT245_SendNack
ret

EnterBootLoader:
  FT245_SendAck;



  wdr
  ; Start timed sequence
  ReadPort WDTCSR, RTemp
  ori RTemp, (1<<WDCE) | (1<<WDE)
  WritePort WDTCSR, RTemp
  ; -- Got four cycles to set the new values from here -; Set new prescaler(time-out) value = 64K cycles (~0.5 s)
  ldi RTemp, (1<<WDE)
  WritePort WDTCSR, RTemp


  WritePortValue WDTCSR , (1<<WDE)
  EnterBootLoaderWait:
  rjmp EnterBootLoaderWait

SendVersion:
ldi RCommandByte,'>'
FT245_SendByte RCommandByte
ldi RCommandByte,3
FT245_SendByte RCommandByte
ldi RCommandByte,VersionHigh
FT245_SendByte RCommandByte
ldi RCommandByte,VersionLow
FT245_SendByte RCommandByte
FT245_SendAck
ret

;Sets the ext port
ExtPort:
  FT245_WaitForRead_PayLoad LedAlternateBlink
  FT245_ReadByte RData
  FT245_SendAck
  WritePort ExtPort,RData
ret

;Clears the data buffer
ClearDataBuffer:
  SetPortBit Led_Port,Led_Yellow_Bit
   
  FT245_SendAck
  LDI XH,HIGH(DataBuffer)
  LDI XL,LOW(DataBuffer)

  ldi RBufferLoopCounterHigh,HIGH(DataBufferSize) 
  ldi RBufferLoopCounter,LOW(DataBufferSize)

  ldi Rtemp,0
  ClearDataBufferLoop: 
     ST X+,RTemp
	 sbiw RBufferLoopCounter,1
   brne ClearDataBufferLoop 

  ClearPortBit Led_Port,Led_Yellow_Bit

ret

//Receives data from the FT245
ReceiveData:
  SetPortBit Led_Port,Led_Yellow_Bit
  //Read number of bytes to receive
  FT245_WaitForRead_PayLoad LedAlternateBlink
  FT245_ReadByte RBufferLoopCounterHigh
  nop
  nop
  FT245_WaitForRead_PayLoad LedAlternateBlink
  FT245_ReadByte RBufferLoopCounter
      



  SetPortBit Led_Port,Led_Yellow_Bit
  ClearPortBit Led_Port,Led_Red_Bit


    //Load starting address of data buffer
  LDI XH,HIGH(DataBuffer)
  LDI XL,LOW(DataBuffer)

  ReceiveData_Loop:
    FT245_WaitForRead
    FT245_ReadByte RData
	st x+,RData
  //     FT245_SendByte RData
  //    FT245_SendByte RBufferLoopCounterHigh
//	  FT245_SendByte RBufferLoopCounter
  
  sbiw RBufferLoopCounter,1
  brne ReceiveData_Loop 
  FT245_SendAck

  ClearPortBit Led_Port,Led_Yellow_Bit

ret
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
